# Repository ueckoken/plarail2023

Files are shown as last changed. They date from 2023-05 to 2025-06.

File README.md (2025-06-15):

# plarail2023

プラレールをIoT化して自動制御します

## これはなに？

このリポジトリでは電気通信大学工学研究部のプラレール企画のコードやドキュメントを管理しています。

## ドキュメント

プラレール企画に関する情報は以下のリンクにまとめます。

[https://ueckoken.github.io/plarail2023/](https://ueckoken.github.io/plarail2023/)

## コントリビュータのみなさんへ

GitHub Actions による CI/CD を走らせるために main ブランチへの直接コミットを禁止しています。 プルリクエストを発行してください。

PR の Reviewer には似たような PR で指定されている人を指定してください。内容ごとにタグを付けているので調べるときはぜひ活用ください。

PR が Approve されたら PR の Author が直接マージして下さい。

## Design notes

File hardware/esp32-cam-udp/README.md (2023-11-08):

# ESP-CAM-UDP

ESP32→(UDP)→NodeJS→(WebSocket)→browser

800x600 30fps 200ms

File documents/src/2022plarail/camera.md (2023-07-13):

# カメラ配信

## 車載カメラ配信

ESP-EYEというマイコンボードを一部のラジコン化したプラレールの先頭に取り付けており、車両からの映像を見られるように実装を行いました。ESP-EYEは、小さいながら単体でWi-Fi接続できてWebカメラとして利用することができる便利なボードです。

今回はプログラムとして[esp32-cam-mjpeg](https://github.com/arkhipenko/esp32-cam-mjpeg)を利用したのですが、これはESP-CAM側でストリーミングサーバーを建ててそこにアクセスするとmjpeg形式で動画がストリーミングされるというものです。そのため、単体ではWebRTCに直接配信できないので、canvasに描画されたmjpegをcaptureしてstreamを生成して、そのstreamをSkyWayに配信する配信用のサイトを構築して配信を行いました。これにより、ESP-CAMに接続されるクライアントが1つに限定されることでESP-CAMへの負荷も軽減されています。

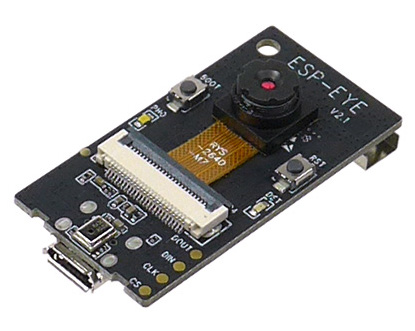
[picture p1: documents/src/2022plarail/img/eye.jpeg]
ESP-EYE


## Webカメラ配信

会場内の各所に設置されたWebカメラから各駅の現状を配信するために、SkyWayを用いて配信サイトを構築しています。仕組み自体は単純で、会場内にWebカメラとノートパソコンを設置しておき、配信用のサイトから駅ごとに固定のRoomIdで入室してカメラ映像の配信を行っています。

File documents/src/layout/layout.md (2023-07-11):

# レイアウト

2023.07.11現在のレイアウト案は以下の通りです。

```mermaid
flowchart LR
  shinjyuku["新宿(1)"]
  sakurajosui["桜上水(2)"]
  syako["車両基地"]
  chofu["調布(2)"]
  hashimoto["橋本(1)"]
  hachioji["京王八王子(1)"]
  syako --> chofu
  shinjyuku --> sakurajosui
  sakurajosui --> shinjyuku
  sakurajosui --> chofu
  chofu --> sakurajosui
  chofu --> hashimoto
  hashimoto --> chofu
  chofu --> hachioji
  hachioji --> chofu
  shinjyuku --> syako
```

```mermaid
flowchart LR
  s0 --> sa0
  sa0 --> ch0
  ch0 --> ha0
  ha0 --> ha1
  ha1 --> ch1
  ch1 --> sa1
  sa1 --> s1
  s1 --> s0
  ch0 --> hac0
  hac0 --> hac1
  hac1 --> ch1
  s0 --> pool
  pool --> ch0 
```

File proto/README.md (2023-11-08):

# protocol

全体で利用するProtobufを定義ファイルを格納するディレクトリです。

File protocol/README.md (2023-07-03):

# protocol

全体で利用する定義ファイルを格納するディレクトリです。

protobufやgraphQLを保存することを想定しています。

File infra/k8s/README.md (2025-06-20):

# Plarail2023 Kubernetes Deployment

このディレクトリには、Plarail2023プロジェクトをKubernetesで動かすためのマニフェストが含まれています。

## 前提条件

- Kubernetesクラスター（シングルノード）が動作していること
- `kubectl`がインストールされ、クラスターに接続できること
- Dockerがインストールされていること（ローカルビルドの場合）

## ディレクトリ構造

```
infra/k8s/
├── base/                    # 基本的なKubernetesリソース
│   ├── mongodb/            # MongoDB + Mongo Express
│   ├── emqx/              # EMQXメッセージブローカー
│   ├── state-manager/     # State Managerサービス
│   ├── auto-operation/    # 自動運転サービス
│   ├── frontend/          # フロントエンドダッシュボード
│   ├── proxy/             # プロキシサービス
│   └── nginx-ingress/     # Nginx Ingressルール
├── overlays/              # 環境別の設定
│   └── local/            # ローカル開発環境用
├── build-images.sh       # Dockerイメージビルドスクリプト
├── deploy.sh            # デプロイスクリプト
└── install-nginx-ingress.sh  # Nginx Ingress Controllerインストールスクリプト
```

## デプロイ手順

### 1. Dockerイメージのビルド

```bash
cd infra/k8s
./build-images.sh
```

### 2. Kubernetesへのデプロイ

```bash
./deploy.sh
```

このスクリプトは自動的にnginx-ingress-controllerがインストールされているか確認し、
必要に応じてインストールを行います。

## サービスへのアクセス

### NodePort経由

- Frontend (Ingress経由): http://localhost:30080
- EMQX Dashboard: http://localhost:31808
  - ユーザー名: admin
  - パスワード: password
- Mongo Express: http://localhost:30081
  - ユーザー名: admin
  - パスワード: password
- MQTT: localhost:31883
- Proxy (直接): http://localhost:30031

### Nginx Ingress経由（推奨）

deploy.shスクリプトは自動的にnginx-ingress-controllerをインストールします。
以下のURLでアクセス可能（すべてhttp://localhost:30080経由）：

- Frontend: http://localhost:30080/
- State Manager API: http://localhost:30080/api/
- EMQX Dashboard: http://localhost:30080/emqx/
- Mongo Express: http://localhost:30080/mongo-express/
- Proxy: http://localhost:30080/proxy/

### 手動でnginx-ingress-controllerをインストールする場合

```bash
# Helmを使用してインストール
./install-nginx-ingress.sh
```

## 管理コマンド

### ステータス確認

```bash
# すべてのリソースを確認
kubectl -n plarail get all

# Podのログを確認
kubectl -n plarail logs -f deployment/state-manager
```

### 削除

```bash
# すべてのリソースを削除
kubectl delete -k overlays/local/

# Namespaceごと削除
kubectl delete namespace plarail
```

## トラブルシューティング

### Podが起動しない場合

```bash
# Podの詳細を確認
kubectl -n plarail describe pod <pod-name>

# イベントを確認
kubectl -n plarail get events --sort-by='.lastTimestamp'
```

### PVCがPendingの場合

ローカル環境でStorageClassが設定されていない場合は、以下を実行：

```bash
# デフォルトのStorageClassを作成
kubectl apply -f - <<EOF
apiVersion: storage.k8s.io/v1
kind: StorageClass
metadata:
  name: standard
  annotations:
    storageclass.kubernetes.io/is-default-class: "true"
provisioner: kubernetes.io/no-provisioner
volumeBindingMode: WaitForFirstConsumer
EOF
```

## カスタマイズ

### イメージタグの変更

`overlays/local/kustomization.yaml`でイメージタグを変更できます：

```yaml
images:
  - name: plarail2023/state-manager
    newTag: v1.0.0  # 任意のタグに変更
```

### 環境変数の追加

各サービスのdeployment.yamlで環境変数を追加できます。

### リソース制限の設定

本番環境では、各コンテナにリソース制限を設定することを推奨します：

```yaml
resources:
  requests:
    memory: "256Mi"
    cpu: "250m"
  limits:
    memory: "512Mi"
    cpu: "500m"

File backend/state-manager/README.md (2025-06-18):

# State Manager

State Managerは、プラレールシステムの状態を管理するサービスです。

## 修正された問題点

### 1. エラーハンドリングの改善
- `log.Fatal`の使用を削除し、適切なエラーハンドリングに変更
- MQTTハンドラーのStart()メソッドの戻り値処理を修正
- リカバリーミドルウェアを有効化してパニック時のクラッシュを防止

### 2. リソース管理の改善
- データベースカーソルの適切なクローズ処理を追加
- データベース操作にタイムアウトを設定
- シャットダウン時のデータベース接続クローズ処理を追加

### 3. 設定の柔軟性向上
- 設定ファイルのパスを環境変数で指定可能に
- TLS設定のエラーハンドリングを改善

## 必要な環境変数

以下の環境変数を`.env`ファイルまたはシステム環境変数に設定してください：

```bash
# MongoDB接続設定
MONGODB_URI=mongodb://localhost:27017

# MQTT接続設定
MQTT_BROKER_ADDR=ssl://your-mqtt-broker:8883
MQTT_USERNAME=your-username
MQTT_PASSWORD=your-password
MQTT_CLIENT_ID=state-manager-001

# アプリケーション設定
APP_ENV=dev  # dev, test, prod

# オプション：設定ファイルのパス（デフォルト: ../settings/esp）
SETTINGS_PATH=/path/to/settings/esp
```

## TLS証明書

MQTTブローカーへの接続にはTLS証明書が必要です。`emqxsl-ca.pem`ファイルを実行ディレクトリに配置してください。

## 起動方法

```bash
# 開発環境
go run cmd/main.go

# 本番環境
APP_ENV=prod ./state-manager
```

## トラブルシューティング

### サービスが起動しない場合
1. 環境変数が正しく設定されているか確認
2. MongoDBが起動しているか確認
3. MQTTブローカーが起動しているか確認
4. TLS証明書ファイルが存在するか確認

### サービスが落ちる場合
1. ログを確認して具体的なエラーメッセージを特定
2. MQTTトピックの形式が正しいか確認（`target/id/method`の形式）
3. データベース接続が安定しているか確認

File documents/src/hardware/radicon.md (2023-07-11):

# ラジコン

ラジコンに関してはTWILITEを用いた速度制御を行うことで安定性の向上を目指したい。
基盤に関しては昨年にスバル君が作ってくれたものがあるので、今回はこれを基盤におこして小型化を目指したい。
また重心問題にも対応できるなら尚良い。

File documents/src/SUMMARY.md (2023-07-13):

# Summary

- [このドキュメントは何なのか](./topPage.md)
- [アーキテクチャ](./archtecture/archtecture.md)
  - [自動運転システム](./archtecture/auto_operation/outline.md)
    - [アルゴリズム](./archtecture/auto_operation/algorith.md)
- [ソフトウェア](./software/software.md)
  - [アルゴリズム](./software/algorithm/algorithm.md)
  - [プロトコル](./software/protocol/protocol.md)
    - [Protobuf](./software/protocol/protobuf.md)
- [ハードウェア](./hardware/hardware.md)
  - [ラジコン](./hardware/radicon.md)
- [レイアウト](./layout/layout.md)
  - [必要パーツ](./layout/item.md)
- [2022年プラレール企画](./2022plarail/2022plarail.md)
  - [システム構成図](./2022plarail/systemDiagram.md)
  - [レイアウト](./2022plarail/layout.md)
  - [状態管理](./2022plarail/state.md)
  - [自動運転](./2022plarail/automation.md)
  - [管理サイト](./2022plarail/site.md)
  - [カメラ配信](./2022plarail/camera.md)
  - [インフラ](./2022plarail/infra.md)
  - [ラジコン](./2022plarail/radicon.md)

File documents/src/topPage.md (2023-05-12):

# このドキュメントは何なのか

このドキュメントはプラレール企画についてのシステムだったり技術だったりの情報をまとめるために作りました。
ドキュメントを残すことで後輩への引き継ぎや初めて参加する人への説明をやりやすくしようという目的があります。
なのでみなさんドキュメントを書いていってくださいね。

## プラレール企画とは

プラレール企画は2020年の調布祭から始まった、プラレールを制御してみようという企画です。
やっていることは毎年少しずつ違っていますが、主にはポイント制御、車両の速度制御などを行っています。

## 2023年のプラレール企画の予定

2022年のプラレール企画が諸事情で爆散したので、2023年は2022年でのプラレール自動制御などを引き続きやっていくことになると思います。

また、システム構成についても見直して作り直そうということになっています。

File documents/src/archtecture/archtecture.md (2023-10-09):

# アーキテクチャ

2023.10.00時点での最新版のアーキテクチャ

```mermaid
flowchart RL

subgraph エッジデバイス
MQTTHandler <-->|"MQTT"| 通過在線検知センサー
MQTTHandler <-->|"MQTT"| ポイント制御器
end

subgraph 状態管理
管理画面 <-->|"connect"| StateManager
MQTTHandler <--> StateManager
StateManager <--> DB1[(state_db)]
end

subgraph 自動運転
AutoOperater <-->|"connect"| StateManager
AutoOperater <--> DB2[(diagram_db)]
AutoOperater <-->|"connect"| 管理画面
end

subgraph 映像配信
Webカメラ --> |"USB"| 配信サイト
ESP-EYE -->|"mjpeg"| 配信サイト
配信サイト -->|"WebRTC"| SkyWay
SkyWay -->|"WebRTC"| 管理画面
end

```

## 自動運転
昨年度は実装できなかった部分であるので、1から実装をする必要がある。
アルゴリズムの実装に関してはすでに#7にて議論している。路線の状態をグラフとして管理をする。
アルゴリズムにデータを渡すために色々をしなくてはいけないので、その部分に関しては別途実装する。

## 管理サイト
基本的にやりたいこととしては去年のサイトと同じだが、今回は状態を同期するためのプロトコルとしてconnect-webを採用したい。また、プラレールのレイアウトが微妙に変化することが予想されるのでフロントエンドの調整（SVG手打ち芸）が必要だが、可能ならこの部分を簡単にできるとなおよい。

## 状態管理
これまでとは異なるアーキテクチャで、列車の状態管理をモダンなIoTのアーキテクチャに近づけていきたい。
AWS IoTやAzureなどで利用されているアーキテクチャを模倣する感じで、MQTTでエッジの端末と通信してIOの状態の対応付けをバックエンド側で行うようにする。この部分は正直なところ、MongooseOSなどの既存の仕組みがあるが余裕があれば独自実装したい。
これまでは、KVSで管理していたがPodが死ぬと状態が失われるためアーキテクチャとしてはあまり良くない。
今回はアクセス頻度などを考慮して、MongoDBなどのNoSQLなDBで状態管理を行いたい。

## 列車検知
これまでのホールセンサーやCdSでは読み飛ばしが多くあった。今回はそうしたデータの読み飛ばしをなくすために、マイクロスイッチを用いた列車の通過検知と、列車が駅に停車した際にNFCタグを用いて列車を識別するような仕組みを実装したい。
基本手にはハードウェア側で大規模な処理をするわけではなく、イベントをhttp経由で通知してくれれば良い。（MQTTを採用するメリットは薄いような気もするがプロトコルの検討は必要かも）

## ポイント・ストップレール制御
昨年度と同様にESP32にサーボモータを接続して制御を行うことを検討している。
昨年度からの違いとして、MQTTでブローカーと接続してあげることで現地会場でのサーバー構築作業がなくなるので良さそうかなと思っている。httpよりも薄い感じのプロトコルらしく、普通にESPで問題なく動きそう。
ベースとなるコードはあるものの、実装が大きく変わるのでソースコードの変更は必要。

## カメラ配信
昨年度と同様にしてSkyWayを用いた映像中継を検討している。
車載カメラにはESP-EYEを採用してmjpegなどで受け取った映像を配信用PCからSkyWayに流すことを検討。
旧SkyWayがサービス終了するらしいので実装の変更は必要かもしれない。

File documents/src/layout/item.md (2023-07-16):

# 必要なレール一覧

[公式サイト](https://www.takaratomy.co.jp/products/plarail/lineup/rail/)を参考に必要なレールを検討。

## レール一覧

| コード | 商品名 | 必要本数 | 単価 | 個数 |
|:---:|:---:|:---:|:---:|:---:|
| R-01 | 直線レール | 12 | 300(4本) | 3 |
| R-03 | 曲線レール | 4 | 302(4本) | 1 |
| R-04 | 複線直線レール | 21 | 635(4本) | 6 |
| R-05 | 複線曲線レール | 10 | 587(4本) | 3 |
| R-06 | ニュー坂レール | 4 | 573 (2本) | 2 |
| R-08 | ストップレール | 15 | 507(2本) | 8 |
| R-10 | Uターンレール | 3 | 582 | 3 |
| R-11 | ターンアウトレール | 4 | 330(2本) | 2 |
| R-15 | 複線幅広ポイントレール | 12 | 540(2本) | 6 |
| R-24 | 複線わたりポイントレール | 2 | 577(2本) | 1 |
| R-28 | 複線ターンアウトレール | 2 | 786(2本) | 1 |
| J-14 | ブロック橋脚 | 12 | 669(6個) | 2 |
| J-22 | 複線ブロック橋脚 | 6 | 840(6個) | 1 |

## 合計金額

ヨドバシ.comにて見積もりをした結果，合計金額は`￥20,766`となった。([見積書](./estimate.pdf))

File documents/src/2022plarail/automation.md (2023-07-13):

# 自動運転

今年度の大きな新たな取り組みの1つが列車の自動運転です。

色々な方法があるので非常に悩んだ部分です。計画当初は、列車の位置をホールセンサーを用いて把握して、その位置に基づいてポイントを切り替えるようなシステムを想定しており、ポイントと列車の状態の管理に悩んででいました。

そんな中、Maker Fair Tokyoに訪れた際に「[東京大学プラレーラーズ](https://plarailers.com/)」さんという団体がまさにプラレールの自動運転を行なっていたので色々とお話を伺っていたところ、コラボのお誘いを受け調布祭でのコラボが実現しました。

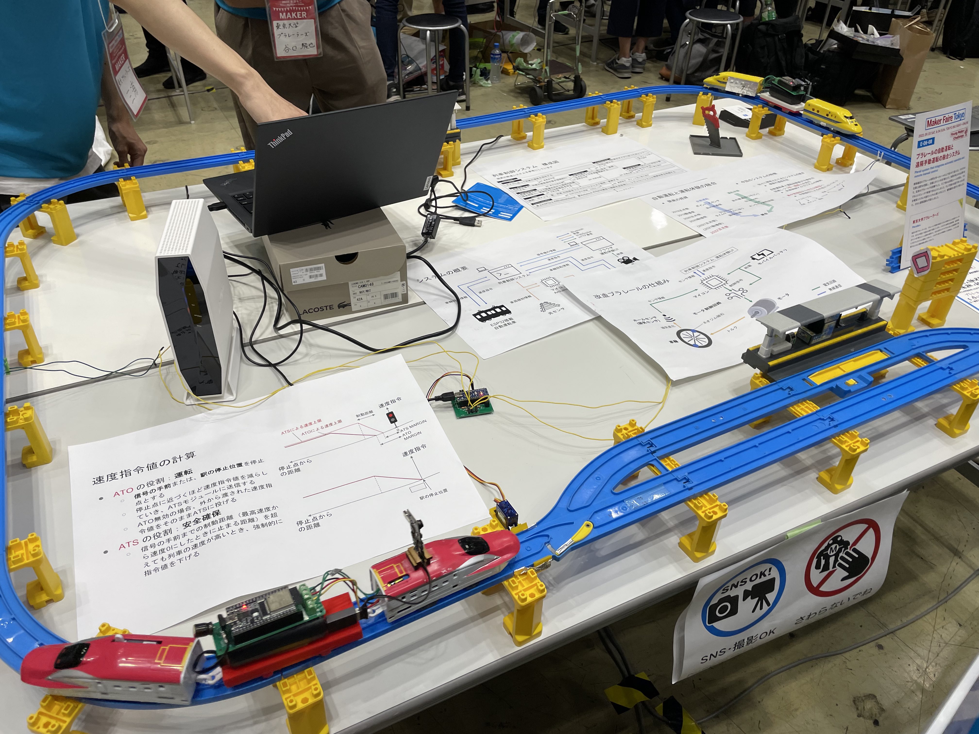
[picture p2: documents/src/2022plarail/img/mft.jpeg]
MFT


調整を行ったところ現在工研が開発しているシステムと組み合わせることが可能と言うことがわかり、プラレーラーズさんが実装した自動運転システムをauto operationとして組み込みました。

## 自動運転の仕組みについて

システムの詳細に関しては、プラレーラーズさんの資料やコードを参考にしていただきたいですが簡単に。

自動運転システムでは、配線図に示している`chofu_b5`のようなストップレールとホールセンサーからなる閉塞区間によって列車の位置を管理しています。プラレーラーズさんによるシミュレーションの画面のような感じです。列車ごとにダイヤを設定しており、それの列車の位置に応じてポイントとストップレールの切り替えを行っているようです。

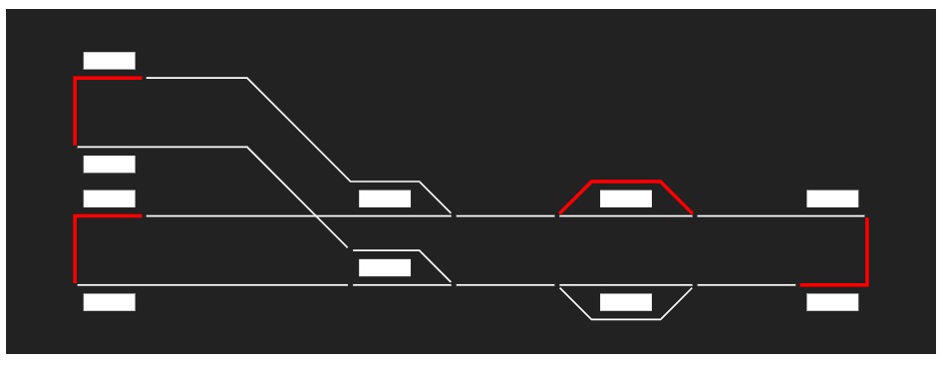
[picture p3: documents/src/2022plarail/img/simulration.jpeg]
シミュレーション


プラレーラーズさん側のシステムと工研のシステムでは扱っている情報や処理が異なるのですが、インターフェース部分や内部での値の取り扱いを工夫することによって連携を行っています。

ホールセンサーは、プラレールの車両の底の部分に取り付けられたネオジウム磁石の磁気を検知するセンサです。このセンサを用いることによって、列車がセンサーを通過したことを検知しています。検知したということを、jsonフォーマットのhttp経由でjson2grpcに送信してサーバーでgRPCに変換してauto operationに通知を行うようになっています。

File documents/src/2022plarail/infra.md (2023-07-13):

# インフラ

externalやinternalなどのサーバー群はすべてKubernetes基盤上にデプロイされます。Fluxcdを用いてGitOpsを実現しており、GitHubにてmanifestsを管理しています。

また、GitHub Actionと組み合わせてCI/CDを行っておりdeploymentのbranchにmergeされるとイメージがビルドされます。イメージの更新を検知するプログラムが走っているため、自動的にデプロイが更新されるようになっています。

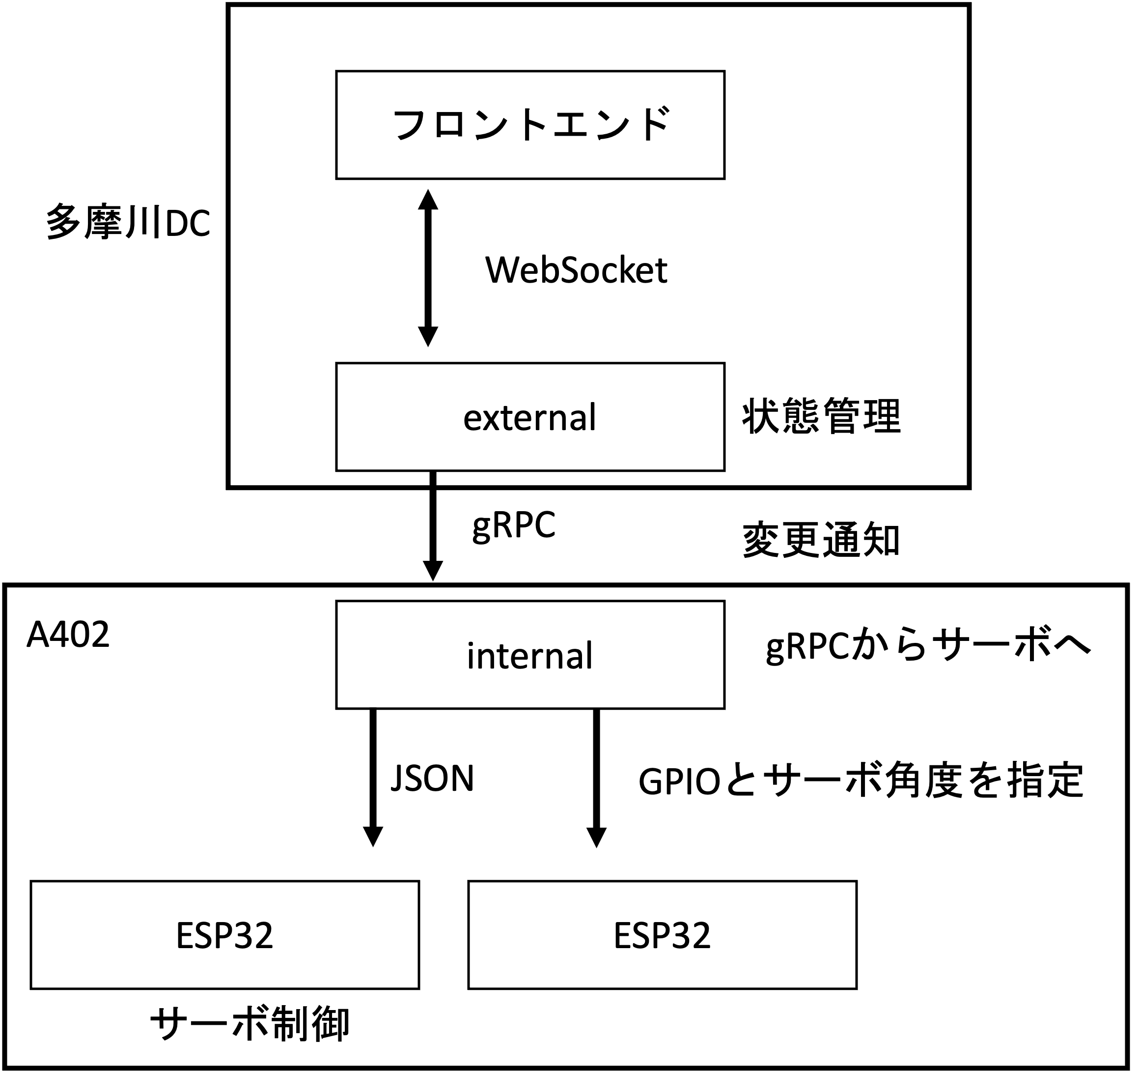
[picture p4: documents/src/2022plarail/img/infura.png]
インフラ構成


インフラの物理的な構成の概略を図に示します。

ここでは大きく、現地会場であるA402教室と多摩川DCに分かれています。現地会場では、デスクトップPCを配置しており、UbuntuのVM上でk3sを動かしています。多摩川DCは、20のごっちさんに提供していただいた自宅サーバー環境です。基本的にESP32と同一ネットワーク内に存在する必要があるinternalを除いて、externalやフロントエンド、auto operationなどはすべて多摩川DCに配置されています。

A402側でinternalサーバーをホスティングするために、大学に申請してグローバルIPを提供していただき、教室に設置したRTX1210をルータとしてネットワークを構築しています。

大まかなインフラ構成自体は昨年のプラレール企画とあまり変わっていないので、詳しくは昨年度のプラレール企画の記事や[ごっちさんのブログ](https://gotti.dev)を参考にしていただければ幸いです。

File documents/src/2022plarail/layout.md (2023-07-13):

# レイアウト

今年度のレイアウトを以下に示します。今年度は教室の関係で、昨年度よりも少し狭いレイアウトになりましたが、スペースを上手く活かして京王線を再現しました。

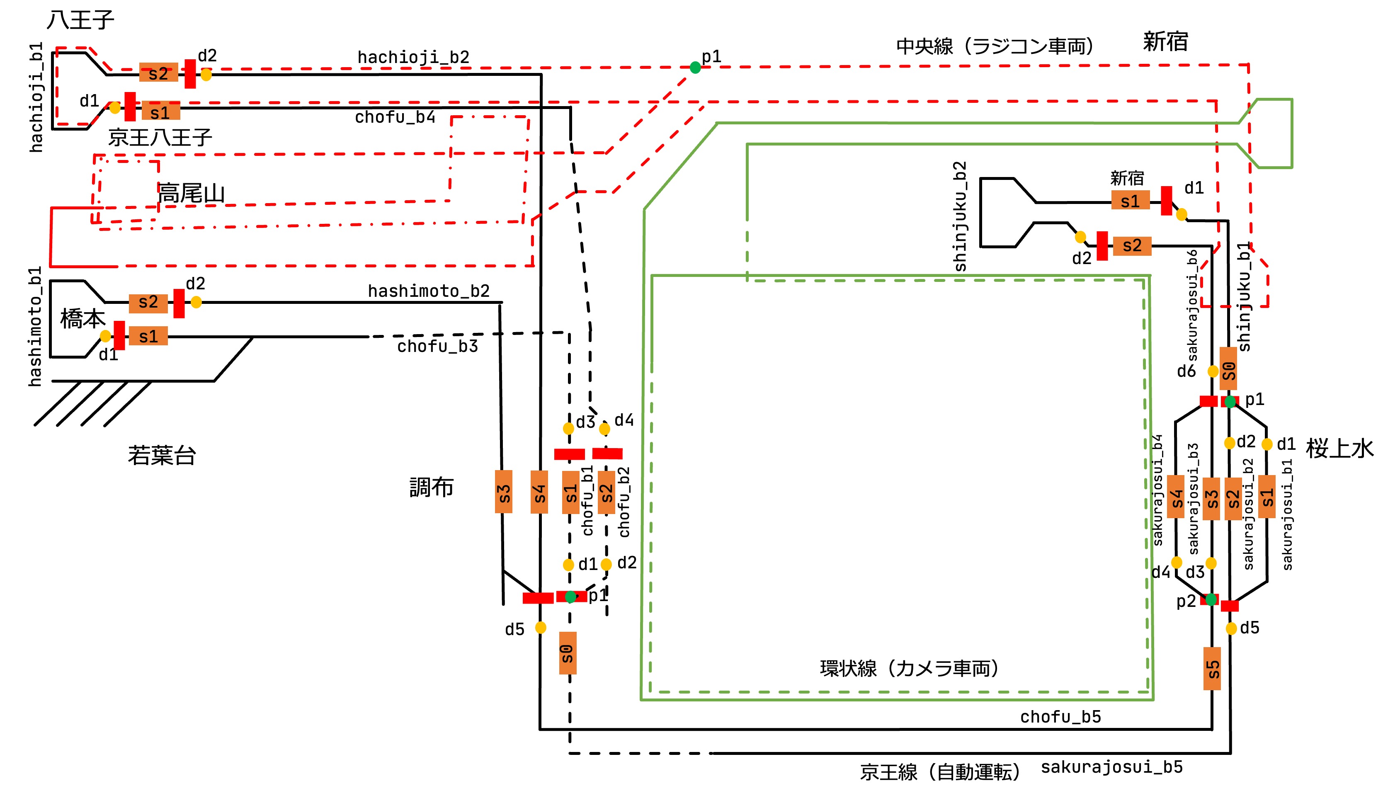
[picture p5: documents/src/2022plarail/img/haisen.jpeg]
配線図

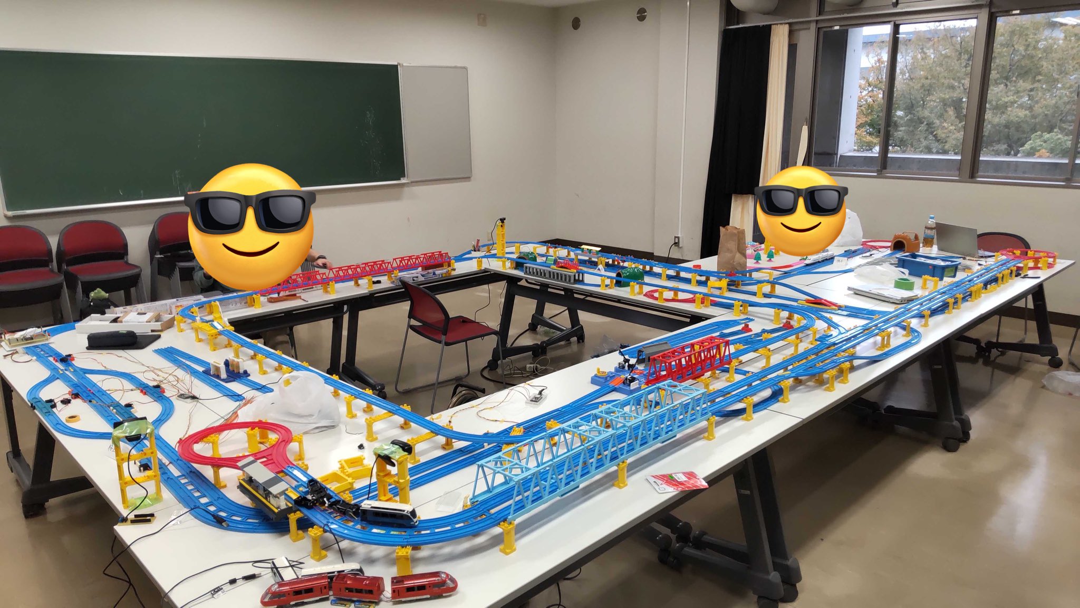
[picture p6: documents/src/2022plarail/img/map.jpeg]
配線した様子


いくつか路線がありますが京王線がシステムによる遠隔制御路線で、そのほかの中央線や環状線はラジコンが走る専用路線を担っておりポイントやストップレールの制御は行なっていません。

桜上水に待避線を用意して通過待ちを可能にしたり、調布駅を立体交差化したりと工夫しています。新宿駅のホームがなんで2つなんだ！というツッコミもあるかと思いますが、そこはバーチャル京王線ということで。

昨年度の反省（昨年は岩本町駅のように1つのホームに両方向の列車が来るようなパターンが存在していたためポイントの状態管理で組合せ爆発したり、列車が正面衝突する事故が多発しました）を生かして、ソフトウェア設計が難しくならないように物理的に調整したレイアウトになっており、列車が必ず一方通行に流れるように工夫しています。

プラレールに関しては、鉄道研究会から貸していただきプラレールの車両に関してはラジコン車両は主に工研で用意しました。

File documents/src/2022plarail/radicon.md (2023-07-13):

# プラレールラジコン化計画

## プラレールって？
プラレールとは古来より男児たちを中心に遊ばれている電車の形状をした玩具である。JR、私鉄を含む
豊富な車両があり、果てにはモノレールのプラレールも存在する。そんな男児なら一度は触ったことがあるであろうプラレール、その構造は実にシンプルなものだ。
電源を入れたらモーターが回転し電車がただ走り出すというものだ。端的にいえば前に走るだけであり、その動作は本来制御不能。しかし今回科学の力を用いてプラレールの速度制御を遠隔で行い、ラジコン化させる。

## 製作における要件定義
今回ラジコンプラレールの製作に当たって以下三つの要件を定めて開発を行った。

- 実機コントロールを用いて無線でプラレールをスムーズにリアルタイムで速度制御する。
- 改造の際、プラレールの外見を損なわないように部品を内部に収める。
- 量産しやすいようシンプルな構造にする。

そのため最終的にはラジコンプラレールを量産、調布祭で展示及びユーザーによる運転ができるようにする予定である。

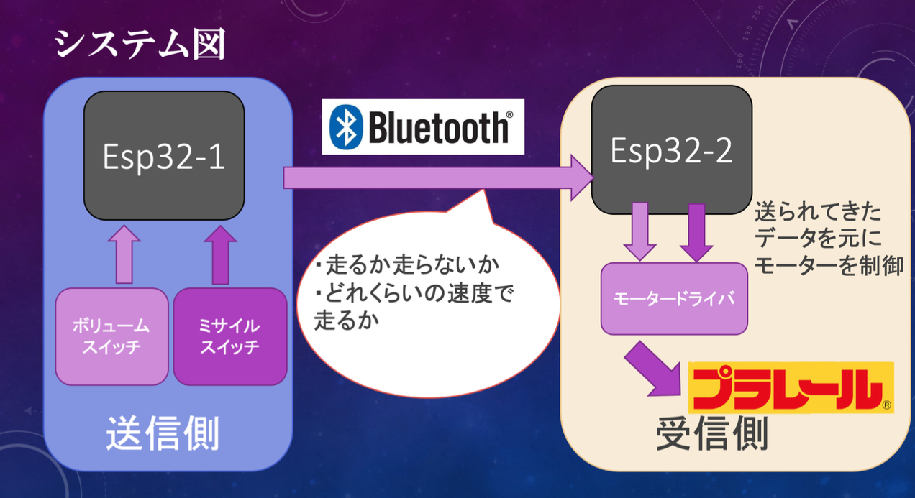
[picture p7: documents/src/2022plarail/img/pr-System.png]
システムズ図


ラジコンプラレールの大まかなシステムは以下の通りである。主にコントロールを担う送信側と、送られてきた
値を元にモーターを制御する受信側に分けられる。間の通信にはBluetoothを用いる。これによりある程度遠くから
運転を行うことが可能になり、消費電力も抑えることができる。

## ハードウェア
### 使用部品

- タカラトミー TAKARATOMY S52 [プラレール 小田急ロマンスカーGSE70000形]  
- ＥＳＰ３２－ＤｅｖＫｉｔＣ　ＥＳＰ－ＷＲＯＯＭ－３２開発ボード×2
-  DＤＲＶ８８３５使用ステッピング＆ＤＣモータドライバモジュール | ＤＲＶ８８３５使用ステッピング＆ＤＣモータドライバモジュール
-  ターミナルブロック　２．５４ｍｍ　２Ｐ　青　縦 | ターミナルブロック　２．５４ｍｍ　２Ｐ　青　縦
-  ピ分割ロングピンソケット　１×４２　（４２Ｐ） | 分割ロングピンソケット　１×４２　（４２Ｐ）
-  ＸＨコネクタ　ベース付ポスト　サイド型　２Ｐ　Ｓ２Ｂ－ＸＨ－Ａ（ＬＦ）（ＳＮ）
-  リチウム電池　ＣＲ１２３Ａ（ＣＲ１２３）
-  ００６Ｐアルカリ電池（積層電池）　９Ｖ　ゴールデンパワー
-  ミサイルスイッチ
-  ボリューム抵抗10k$¥Omega$
-  フルカラーLED

今回は以上の部品を用いてプラレールのラジコンを行った。使用プラレールは小田急ロマンスカーGSE。箱根湯本へ向かう小田急を代表する特急であり先頭車の展望席から見れるダイナミックな眺望が特徴.
車内も広々としていて綺麗なので皆さん是非乗ってみてほしい。新宿箱根湯本区間を約2500円で乗れるぞ！みんな乗ってみよう。

### 回路図

esp32をモータドライバに繋げたシンプルな一体化回路である。モーターとの接続はターミナルブロックを介しており
気軽に付け替えを行えるようになっている。マイコンの電源のみ接触不良を極力避けるためXHコネクタを使用している。
また基盤全体の大きさをプラレールサイズ(32mm×90mm)にとどめており、基本的な中間車に綺麗に収まるようになっている。
そのため外装を戻した際はぱっと見大きな変化が無いように見えるようになっている。
基板はユニバーサル基板なので気合いでハンダづけをしている。

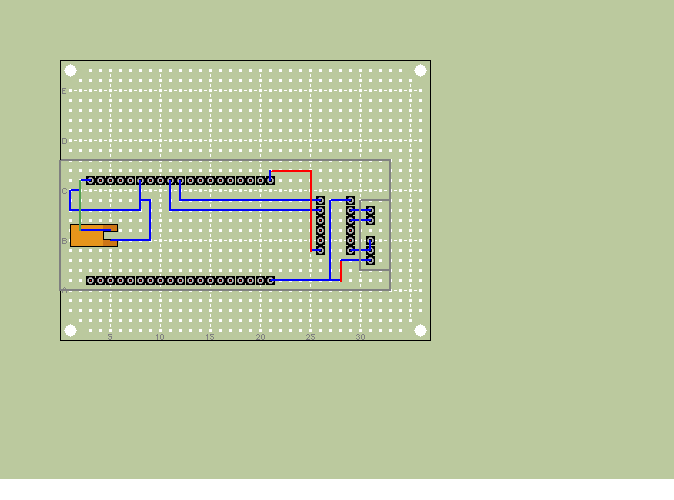
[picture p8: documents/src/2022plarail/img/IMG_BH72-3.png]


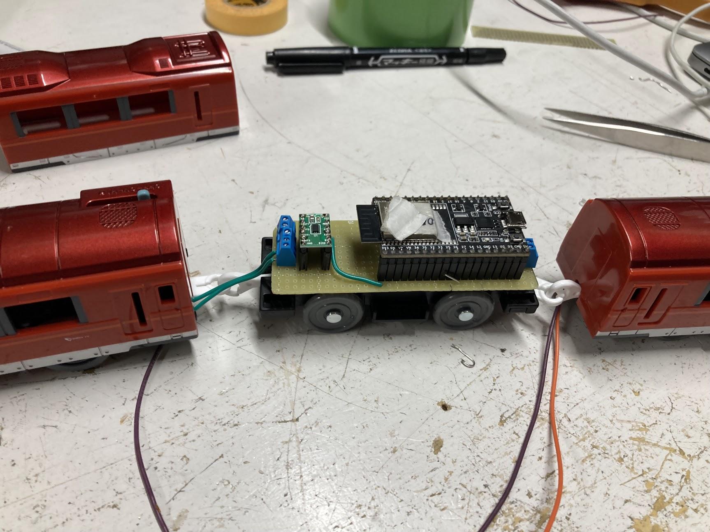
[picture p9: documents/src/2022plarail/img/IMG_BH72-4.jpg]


### プラレールの改造
先頭車に動力、中間車と後尾車は空というのがプラレール車両の基本的な構造である。
そのため、中間車に先ほどの回路、後尾車にバッテリーという車両構成になった。先頭車の動力は
モーターから配線を伸ばす以外の改造はしておらず、重りとして絶縁させた乾電池の搭載を行っている。
また内部に部品を詰める都合上内部の柱は破壊してある。これにより外装を外しやすくなり、気軽にメンテナンスを
行えるようになった。

改造したプラレールの様子である。ぱっと見は元のプラレールとの大きな変化もなく
綺麗に収まった姿になっている。窓から一部のパーツが見えてしまっているが、排熱も兼ねているので何も悪いことだけではない。（上から見れば割とわからんしね…）

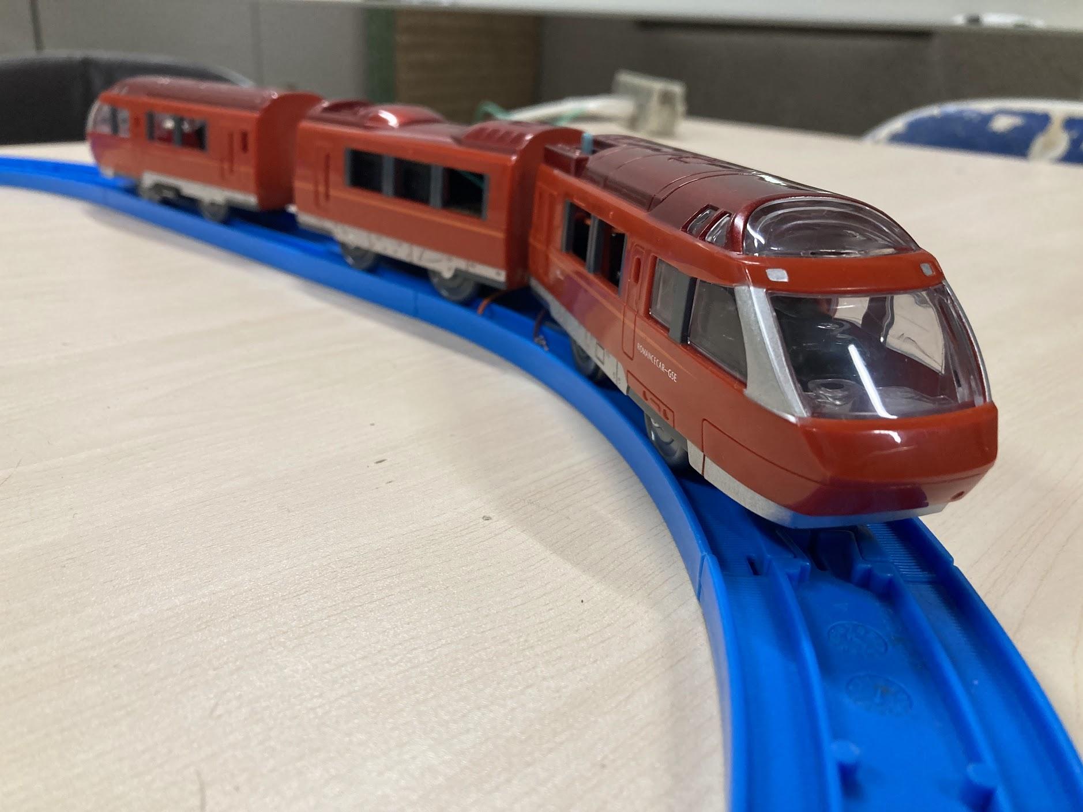
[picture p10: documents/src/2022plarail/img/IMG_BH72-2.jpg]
製作したプラレール車両


### プラレールコントローラー
速度制御はボリューム抵抗を介して行っている。ボリューム抵抗のつまみを回すことでプラレールの速度を制御することができる。
つまみを最大まで回すことでプラレールは最高速で走り出す。
また発車できるか否か、
ちゃんとBluetooth接続がなされているかの確認のため下記の
ようにフルカラーLEDを搭載している。そのため今の状態が視覚的にわかりやすくなっている。
解説するとランプが赤の時、Bluetooth接続が完了したことを表している。この時に（かっこいい）ミサイルスイッチをONにすることで
ランプが青になりプラレールは発信することができる。コントローラーの機能としては最低限あるが
外装はまだ出来ておらず大変大味な仕様となっている。

### バッテリーについて
このラジコンプラレールの中で地味ながらも重要な存在はバッテリーである。
マイコン用の電源とモーター用の電源の二つが必要となり、尚且つ内部に
パーツを収める必要があった。最後尾車にバッテリーは収納したが大きさの制限は大きく
あまり大きい電源を搭載することは出来ない。そこで以下のようにした。マイコン電源はesp32の5V、GNDから供給されており
esp32の電源供給の必要電圧のラインは7~12Vとなっているので9V電池を使用した。
内部のレギュレーターで最終的に3.3Vまで落としてくれるらしいので破損の心配もない。
モーター電源はカメラ用電池で使用されているCR123aを使用。サイズが小さく尚且つ定格電流、電圧も申し分ないという
理由から採用がなされた。

## ソフトウェア

#### 送信側
ペアリングするesp32のMACアドレスを元にまずペアリングを行う。ペアリングは無線イヤホンが飛び交っている状態や
なんか気分によっては繋がりにくい時がある。また受信側のesp32の電源をONにしてからでないと繋がりにくくなる。
というかなんか繋がらない。Bluetooth接続後はコントローラーのランプが赤く光る。この状態でボリュームを回しても電車は
走り出さない。ミサイルスイッチの電源をONにすることでランプが青に代わり発車できるようになる。この辺は信号機の色の変化を意識
している。結局このコントローラーはBluetoothを介して配列型の値を送信しておりスイッチの動作によって配列型の値が変わるようになっている。
今回は主に二つのデータを送信しており発車するか否かと、列車の速度の値である。列車の速度は0~255の256段階となっておりボリュームの位置で決まる。
ボリュームから測ったアナログ入力の値max4095を16で割った数を挿入し送り出しているのだ。Bluetoothからのデータ送信はリアルタイムで行われており
常に速度を制御することが可能となった。また配列型のデータを遅れることからその拡張性はとても大きい。

#### 受信側
速度制御ということでPWM制御を行っている。詳しい説明は先人たちがきっとしているので省くが、Bluetoothを介して送られてきた0~255の値を代入し
任意の速さで動かせるようになっている。余談というべきか、当然の話といえば当然なのだがesp32を使用しているので
スマホからの制御も実は可能である。

## 残る課題と今後の展望
まぁ大体上手くいったのだがまだ課題が多く残っている。

まずこのプラレール車両の構成上満足に前後に走ることが出来ない。
重量バランスが崩れたこともありすぐ脱線したりするのだ。
これの解決策としてプラレールの前後、先頭車最後尾車両方にモーターを搭載するということを考えている。プラレールの車両には
連結することが可能な車両がおり、結果前後にモーター車両が来ることになる。こちらの車両を使用することで満足に前後運転ができるようになるだろうと考えている。
また重量バランスが狂った弊害としてもう1つ電池残量によっては坂を登れなくなってしまった。
中間車後尾車に対して先頭車両が相対的に軽くなってしまい、坂を登る際に前輪がウィリーしてしまうのだ。
これに関してはモーターをより強力なものに換装しかつ先端部に重りを搭載することで解決しようと考えている。

次にコントローラーだがこれはまず見た目が雑すぎるのだ。基板に直接諸々を乗っけたという状態の上外装がないので持ちにくさにも繋がっている。
この辺は改造できる点が多い。まず外装を作り、コントロラー部分をマスコンのようなハンドルへの変更。
せっかく電車を運転しているのでできるならマスコンのようにしたいと考えている。
またプラレールはモーターで動く都合上モーターのノイズしかならない。そこで走行中車両の発車音、走行音がなればより
面白みが出るのではないか？と考えている。カメラを先頭部に取り付けラジコン操作ができるように
なればまさに「電車でGO」である。理想系としてはこの形の完成を目指している。

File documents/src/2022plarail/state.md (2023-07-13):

# 状態管理

IoTシステムの基本的な機能である状態管理を担っているのが、externalとinternalの2つのサービスです。ここら辺のシステムは昨年度のものをそのまま引き継いでいます。

IoTシステムにおける状態管理について簡単に説明すると、システム上の状態と現実のハードウェアの状態を一致させるということです。例えば最近よくあるようなスマホから電気をON/OFFできるようなライトがあった時に、サーバー上ではライトの現在の状態(ライトがついているのか消えているのか)を保持しており、スマホからライトを消すという指示がくるとサーバー上の状態を更新するとともに、現実のライトもOFFにします。もし状態管理がうまくいっていないと、システム上だとライトが消えているのに現実のライトは点いているというような事態に陥ってしまうのでとても重要な部分です。

また、この状態管理によってシステムの状態とハードウェアの状態が一致していることが保証されていると、ソフトウェアではより抽象的にハードウェアを扱うことが可能になります。

さて、今回のシステムではexternalがポイントとストップレールの状態をKVS(Key Value Store)で保持しています。このexternalの状態が変化するとその変化がinternalを介してサーボを制御するESP32に伝わることで現実世界のポイントが動きます。たとえば、`sakurajosui_b1`というストップレールをONにすると、

1. ストップレールをONにするボタンが押される
2. クライアントからexternalのAPIを叩く
3. externalで状態(ON/OFF)を更新して、操作するポイントの名前と状態をinternalへ伝える
4. externalから渡された状態に基づいて、そのポイントを管理するESP32に対してサーボの角度を指定するAPIを叩く
5. ESP32で指定された角度にサーボが動き、ストップレールが動く

というような流れになっておりそれぞれで抽象化されているので、上から下へ流れるにつれてレイヤが下がっていくイメージです。

実装的な面で言うと、externalとinternalはそれぞれgolangで実装され、gRPCを用いて話すようになっており、フロントエンド側からはJSON形式のhttpでリクエストを受けつけるようになっています。ここら辺もconnectとかを使ってprotobufを使うように統一できると良さそうですね。

また、internalのサーバーはESP32と同じネットワーク上に存在しており、ESP32に固定IPを割り振ってそのIPアドレスをinternal側で管理することで実装しています。最近のIoTシステムだと、ESP32から直接クラウド上のサーバーにアクセスして状態の変更を監視するみたいなパターンが多いので少し特殊かもしれません...?

MongooseOSとmDashを使ってクラウドにするぞー！という計画はあったのですが、接続できる台数の制限があったり、1からこの部分のコードを書き直していると他の部分が追いつかないなどがあったので断念しました...。もし次回があればそこらへんも挑戦してみたいです。

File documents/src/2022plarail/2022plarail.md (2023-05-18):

# 2022年プラレール企画

2022年のリポジトリは[こちら](https://github.com/ueckoken/plarail2022)

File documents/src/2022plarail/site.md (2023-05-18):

# 管理サイト

昨年は完全オンライン開催だったため、観客側がポイントを遠隔で操作するために操作用のサイトを用意していました。しかし、今年度は対面開催かつ自動運転であるため基本的に来場者がポイントを操作することはありません。そのため、メンテナンスとモニタリング用にポイント・ストップレールの状態の確認と把握、カメラ映像の確認ができるサイトを構築しました。

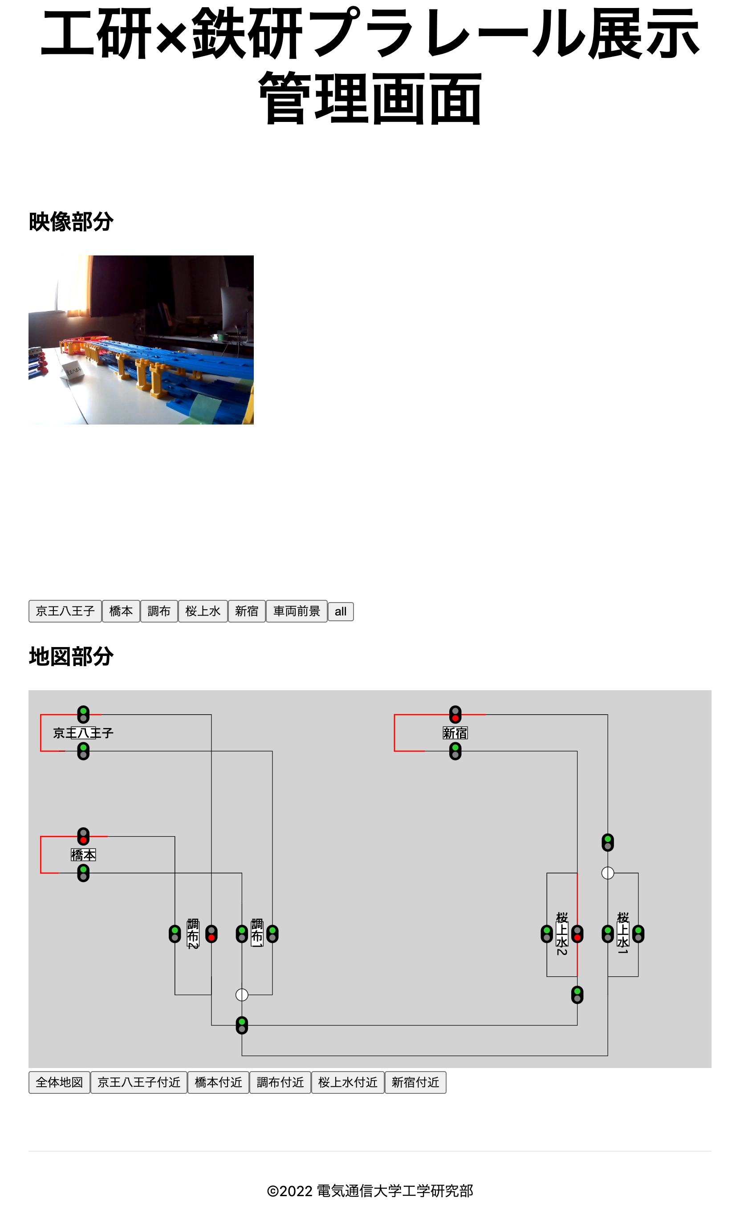
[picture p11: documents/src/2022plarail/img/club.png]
配信画面


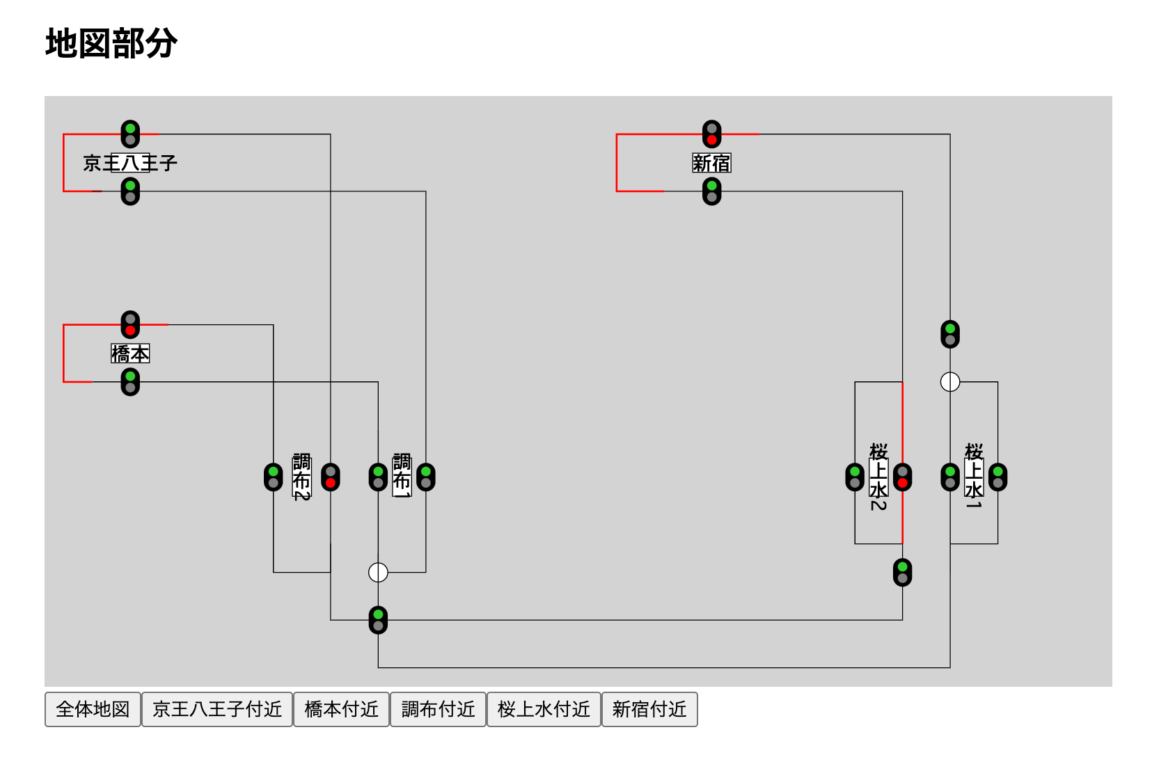
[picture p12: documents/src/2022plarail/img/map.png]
列車の状態表示


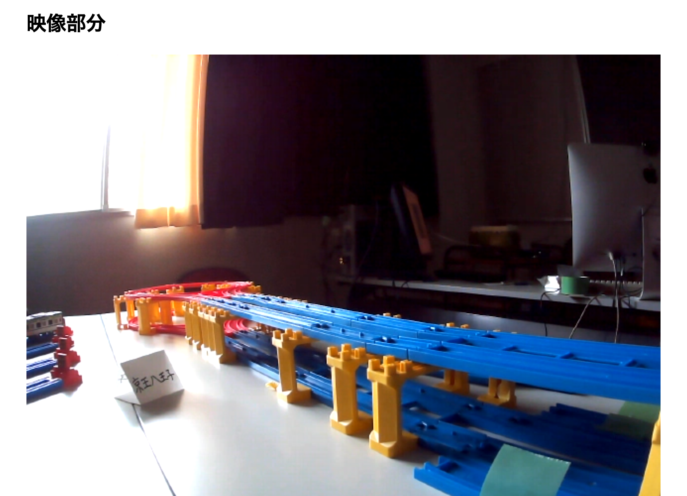
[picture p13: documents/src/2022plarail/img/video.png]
配信映像


管理画面の上部には、会場の各駅ごとに設置されたWebカメラの映像が投影されており一括して状態を確認することができます。画面下部では、現在のレールの状態が表示されています。

それぞれの信号がストップレールと対応しており、クリックするとストップレールのON/OFFが切り替わります。また、分岐になっているところをクリックするとポイントが切り替わります。

フロントエンド側とexternalのサーバー側とでWebSocketにて通信を行なっており、リアルタイムで状態の反映が行われるようになっています。

また、路線上で赤色にハイライトされている部分は閉塞区間が閉になっている部分で、その区間内に列車が存在することを示しています。

フロントエンドの実装は、Next.jsで行っています。昨年度のプラレール企画のものをベースとして今年度のレイアウトへの反映や調整を行いました。

画面下部の状態表示の部分はSVGを直接書き換えて実装しており、ReactでSVGをwrapするComponentを作成して下のように全てのパーツを座標指定して配置してあります。（手打ちで全部の座標を打ち込むのはなかなか辛かったのでツールで自動化したいです...）

```jsx
<Rail
  // hachioji_b2
  positions={[
    { x: 120, y: 40 },
    { x: 300, y: 40 },
    { x: 300, y: 500 },
  ]}
  trains={[]}
  isClosed={blockState["hachioji_b2"]}
/>
```

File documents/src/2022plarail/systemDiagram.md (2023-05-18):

# 2022年のシステム構成図

今年度のシステム構成図を以下に示します。

昨年度のプラレール企画のアーキテクチャを引き継いで今年度に新たにいくつかの機能を追加した形になります。今年度新しく追加した部分は次の通りです。

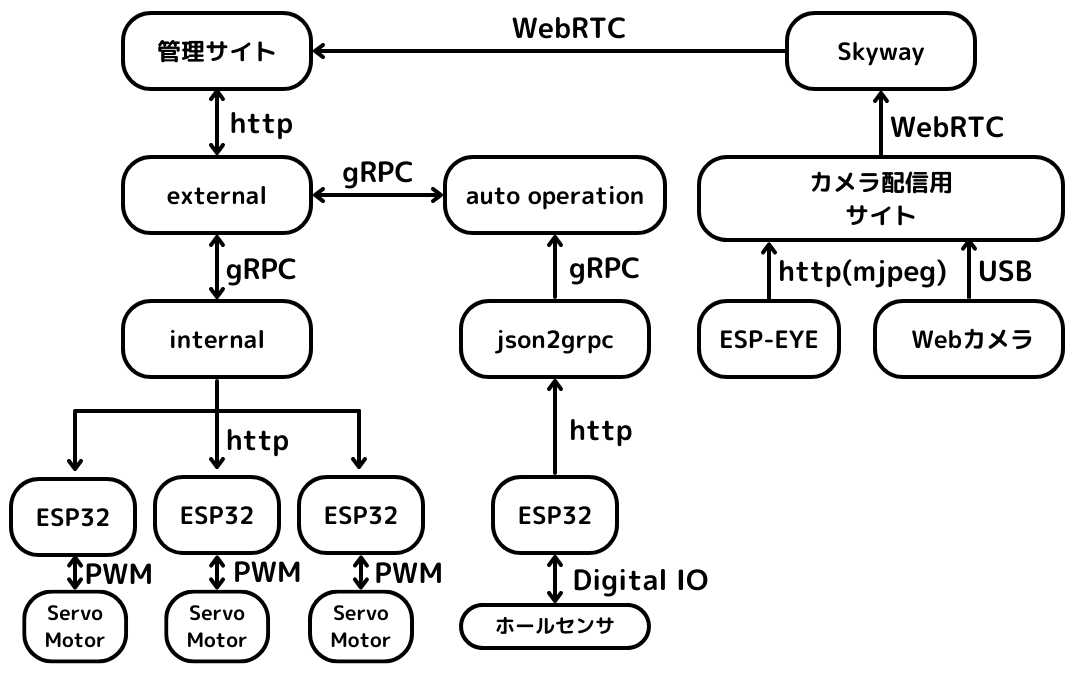
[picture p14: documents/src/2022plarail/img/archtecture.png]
2022年のシステム構成図


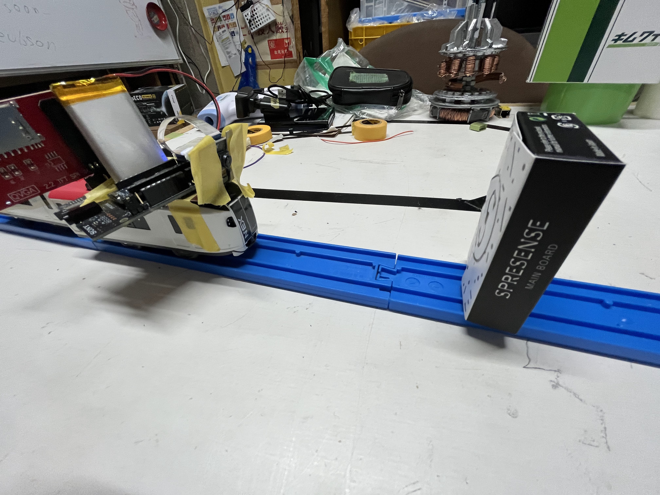
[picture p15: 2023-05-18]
documents/src/2022plarail/img/eltres.jpg

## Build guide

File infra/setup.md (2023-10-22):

# k8sクラスタのセットアップ方法

1. k8sクラスタにログインできるようにする
2. Fluxのインストール
[https://](https://fluxcd.io/flux/installation/)
3. GithubのPAT (Personal Access Token)を取得する。
4. 以下のコマンドを実行する。

```zsh
flux bootstrap github \
--components-extra=image-reflector-controller,image-automation-controller \
--owner=ueckoken \
--repository=plarail2023 \
--branch=main \
--read-write-key \
--path=./infra/manifests
```

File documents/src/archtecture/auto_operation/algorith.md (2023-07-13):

# 自動運転アルゴリズム

列車は以下のようなアルゴリズムに沿って自動運転を行う。

# 概要

全ての列車の位置と閉塞は以下のようなグラフによって管理される。

```mermaid
flowchart LR;
  A["A(1)"]-.-|2|B;
  B["B()"]-->C;
  C["C()"]-->D;
  C-->E;
  D["D(3)"]-->C;
  E["E()"]-->C;
  C-->B;
  B-->A;
```
それぞれのノードが駅，エッジが閉塞を表している。

なお，これ以外に列車は以下のような状態を持つ。
- 列車の位置
- 列車のPriority(列車の種別のようなもの)
- パス(列車が通るべき経路でノードのリスト)

Priorityは0から始まる整数で，値が小さいほど優先度が高い。

## PathPlanner

ある列車の現在の位置と目的地を受け取り，その列車が目的地に到達するためのPathを返す。
PathPlannerはDFSによってグラフを探索して，目的地に到達するまでに通る全てのノードのリスト(Path)を返す。

## TrainController

グラフ上の各ノード対して以下の処理を行う。

なお，この処理はPriorityが高い順番に行う。

```mermaid
flowchart TD
  idstart{{"開始"}}
  idstart --> id0{{"Nodeに列車は存在するか?"}}
  id0 -->|yes| idQ{{"現在の駅のNodeをPathから削除する"}}
  idQ --> id
  id0 -->|no| idend{{"終了"}}
  id{{"列車のPathの長さは0か？"}}
  id -->|yes| id1{{"DiagramManagerから次のPathを取得する"}}
  id1 --> id6
  id6{{"Pathを取得できたか?"}}
  id6 -->|no| idend
  id6 -->|yes| id7{{"Pathを列車にセットする"}}
  id7 --> id2
  id -->|no| id2{{"Pathの最初のNodeを取得する"}}
  id2 --> id3{{"次の目的地までのEdgeは存在するか？"}}
  id3 -->|yes| id4{{"次のNodeまでのEdgeを削除する"}}
  id4 --> id5{{"Nodeから列車の情報を削除する"}}
  id5 --> idend
```

それぞれの操作と条件について説明する。

### Nodeへの列車存在確認  

列車が存在しないNodeに対しては処理をする必要がないので，呼び出された時点で終了する。この処理を実現するために，Nodeは停車している列車のIDを持っている。

### Path
列車には列車が通るべき経路(パス)が設定されている。列車があるノードに停車した際には，現在停車しているノードをパスから削除して次に停車すべきノードをパスから取得する。

これを毎回のノードで実施することによって，最終的に列車は目的地に到達することができる。目的地に到達した時点でPathの長さが0となるので，DiagramPlannerへ問い合わせを行う。

### Edge

現在のノードから次のノードまでのEdgeは1意に定まる。列車はこのEdgeを通らないと次のノードに到達することができないため，駅から発車するためにはこのEdgeが存在する必要がある。

Edgeが存在して，列車が発車しようとする際にEdgeを削除するが，この操作には以下の特例がある。
**Priorityが0の列車はさらに次のノードへのエッジも消す。つまり2つのエッジを削除する**

ただしこの操作を行うには以下の条件がある。

- 中間の駅のCapasityが1より大きいこと

この条件を満たさない場合は，通常通り1つのエッジを削除する。
## DiagramManager

列車の目的地を管理するサービス。
それぞれの列車の目的地を状態として管理しており，TrainManagerからの要求に応じて目的地とPriorityを返す。

それぞれの列車に設定されているPriorityと目的地は管理画面から設定できる。また，それぞれの目的地とPriorityは優先順位付きのQueで管理されている。

基本的には折り返しが可能な2区間での往復運転を行うように設定されることを想定している。ただし，物理的な制約として折り返しができるのは終点のみである。

## 車両の取り出しに関して

車両の取り出しに関しては，以下のような処理を行う。

今回のレイアウトでは車両基地を設けず，駅に停車している任意の列車を取り出してレイアウトから外すことができるようにする。

レイアウトから取り出した車両は，別に用意しているNFCリーダーに車両のIDをかざして，システム上から対応する列車に対して以下の処理を行う。

- 当該列車によって削除されているEdgeが存在する場合は，そのEdgeを復元する
- 当該列車のPathに停車すべきNodeが残っていた場合は，Nodeを全て削除して列車のPathをNULLにする

これにより，どのような状態であっても車両を取り出すことができるようになる。

また，取り出しやすくするためにDiagramPlannerにおいてある駅で停車するという指示もできるようにしておく。

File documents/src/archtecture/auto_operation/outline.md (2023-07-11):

# 自動運転システム

```mermaid
flowchart TD

subgraph 自動運転
TrainController <--> StateManager
DiagramManager --> PathPlanner
PathPlanner <--> TrainController
DiagramManager <--> DB2[(diagram_db)]
DiagramManager <-->|"connect-web"| 管理画面
end

subgraph 状態管理
管理画面 <-->|"connect-web"| StateManager
EventHandler <-->|"connect"| StateManager
StateManager <--> DB1[(state_db)]
end
```

## 用語

プラレール企画で利用する用語の定義を説明する。

ここには2つのレイヤが存在し，列車の走行位置や閉塞の状態をグラフとして管理している`仮想レイヤ`と，実際のプラレール上のストップレールのON/OFFやセンサーの情報を扱う`物理レイヤ`が存在する。

それぞれのレイヤは完全に独立して機能して，`物理レイヤ`の状態は`仮想レイヤ`によって決定され，`仮想レイヤ`の状態の更新は`物理レイヤ`からの情報によって行われる。

### 仮想レイヤの用語

- 閉塞  
現実の鉄道システムからの用語。鉄道の線路を区切る単位。閉塞内には一つの列車しか存在できない。閉塞内に列車が存在する状態を`閉`，存在しない状態を`開`という。

- 閉塞グラフ  
閉塞の関係を表現した有向グラフ。閉塞をエッジ，駅をノードとして表現する。
閉塞が`閉`となっている区間はエッジが存在せず，閉塞が`開`となっている区間はエッジが存在する。また，各ノードは駅の情報以外にその駅に停車している列車の情報を持つ。  
上り線と下り線は別々のノードとして定義して一周するようなグラフであり，あるノードからあるノードへのパスが必ず存在する。

- 列車番号  
それぞれの列車に対して一意に割り当てられる番号。列車の識別に用いる。  
列車IDは各列車に貼り付けられるNFCのIDと一対一対応する。

- 駅のCapacity  
駅に停車できる列車の数を示す。駅に存在するプラットフォームの数と一致する。

### 物理レイヤの用語

- 構内閉塞  
駅に2つ以上のプラットフォームが存在する場合，その駅の閉塞は構内閉塞となる。構内閉塞は駅のCapacityと一致する。なお，構内閉塞は閉塞グラフには含まれない。

- ストップレール  
プラレールにおいて列車を停止させるために利用する特殊なレール。ストップレールのON/OFFを切り替えることで列車を停止させることができる。

- NFCタグ  
プラレールの車両に貼り付けるIDタグ。それぞれのタグには8byte?のIDが割り振られており，このIDと列車の番号の対応付けを行うことで列車の識別を行う。

- NFCリーダー  
プラレールにおいてNFCタグのIDを読み取るために利用するリーダー。それぞれのストップレールの下に設置しており，列車が停止したときにNFCタグのIDを読み取ることができる。

- 通過検知センサー  
プラレールにおいて列車の通過を検知するために利用するセンサー。センサーのON/OFFを切り替えることで列車の通過を検知することができる。物理的にはマイクロスイッチを用いる。

- ESP32  
サーボモータの制御やNFCリーダー，通過検知センサーの制御を行うために利用するマイコン。Wi-Fiを用いて通信を行う。

- サーボモータ  
プラレールのストップレールを制御するために利用するモータ。指示をした角度へ回転する。

## それぞれのサービスの機能
### StateManager

現在の状態を管理するためのサービス。状態をデータベース上に保存して，他のサービスや管理画面からの要求に応じて状態の更新と取得を行う。  
物理レイヤの状態と仮想レイヤの2つの状態を管理する。
### DiagramManager

列車の目的地を決定するサービス。列車ごとに運行情報を管理して，TrainControllerからの要求に応じて目的地を返す。

### PathPlanner

列車の経路を計算するサービス。経路情報のグラフを元にして，DFSによって現在の列車の位置から目的地までの経路を算出して返す。
### TrainController

列車の運行を管理するためのサービス。列車の運行を管理するために必要な情報をStateMangerから取得して，PathPlannerによって計算された経路を元にして列車の運行を制御する。

### EventHandler

列車が通過した場合と停車中の列車からNFCタグのIDを読み取った情報をMQTTを通して受け取り，その情報を元にしてStateManagerに対して状態の更新を要求する。

## 管理画面

現在の状態を確認するための管理画面。StateMangerから状態を取得して表示する。  
また，DiagramManagerに対して運行情報の更新を要求することができる。

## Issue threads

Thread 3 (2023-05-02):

ドキュメントを作る

kienn-HCl, 2023-05-02:
初めて参加する部員がプラレール企画について把握しやすくするために、きちんとドキュメントを整備したい。

kienn-HCl, 2023-05-11:
gh-pagesブランチにmdbookでビルドしたのをデプロイするようにした。
このリポジトリのsetting私いじれないみたいだからGithub Pages の設定やってくれ @csenet

csenet, 2023-05-11:
@kienn-HCl
設定しておいた。
https://ueckoken.github.io/plarail2023
一応、Adminに昇格させておいたので自由にSettings触れるようになったはず。

csenet, 2023-07-16:
ある程度ドキュメントは完成したのでClose

Closed 2023-07-16.

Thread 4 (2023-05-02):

BLEを利用した位置測位の検証

csenet, 2023-05-02:
プラレールにBLEビーコンを搭載することによって測位を実現したい

## メリット
- ホールセンサによる通過検知と比較して安定した検知ができる
- プラレール内部に小型ビーコンを取り付けるだけで良い

## デメリット
- 位置測位のアルゴリズム構築が面倒
- ホールセンサと比較すると費用がかかる

csenet, 2023-06-29:
BLEを用いた位置即位では正確性に欠けるため、別の方法を検討することにする

Closed 2023-06-29.

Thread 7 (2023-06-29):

自動運転用のアルゴリズムを実装する

csenet, 2023-06-29:
# やりたいこと

**MUST**
- 列車が衝突しない

**SHOUD**
- 最悪のパターンが考慮されている
- 車両ごとの優先度が考慮されている(特急や快速など)

# 前提条件

今回のアルゴリズムとしては列車をいわゆるネットワークにおけるパケットのように見立てて、駅をルータとして駅で列車の情報を取得したタイミングでこのアルゴリズムが呼び出されて、列車が次に向かうべき駅とルートが決定される。

列車には優先度と目的地が定められており、一緒に入力として与えられているとする。

# 入力と出力の要件

自動運転用のアルゴリズムに対する入力は任意の有向グラフとして与えられる。
グラフの入力は、連結リストによる入力を想定する。
列車が存在しており現在通行ができない区間（閉塞が閉の区間）に関してはパスが存在しない。
必ずしも最適経路でなくても良いが、なるべく経路数は少ない方が好ましい。

出力結果としては、
- 現在列車がいる位置から出発して良いのか
- 次の列車の目的地はどこか
- 列車が次に通過するエッジの情報
が最低限出力されていれば良い。なお、出力のフォーマットに関してはソフトウェアで扱いやすい形式であれば任意。

また、全ての車両に対して計算を行うため、計算時間はなるべく少ない方が好ましい。

- 優先度の考慮について

現時点では仕組みとして全ての列車が運転停車する形になってしまっているが、可能ならば通過待ちをできるようにしたい。
駅を通過するという処理を実装するためには、列車の優先度を定める必要がある。
この点に関しては多少検討がいるかもしれない。

# 実装の方針

そこまでグラフが複雑になることはないのでDFSで探索するのが良いかもしれない。計算量を抑えるために増加道法など...?

kienn-HCl, 2023-06-30:
増加道法は二部グラフの最大マッチングだったり最大流問題？ってのを解くのらしいから最短経路を求めるアルゴリズムとしては正しくなさそう

csenet, 2023-06-30:
やはりダイクストラ法なのかな

kienn-HCl, 2023-06-30:
うーん、そもそも経路決定で最短経路を求める必要があるんだろうか？
もっと経路の決定の仕方を煮詰めていったら最短経路求める必要なさそうな気がする。
からもうちょっと経路決定アルゴリズムを議論したほうがいいと思うな

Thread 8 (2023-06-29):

アーキテクチャを決定する

csenet, 2023-06-29:
# やりたいこと

実装を始めるにあたって、アーキテクチャを設計する。

# 実装の方針

前年度の内容をもとにして、今年度やりたいことをもとにしてソフトウェアとハードウェアを含めた全体のアーキテクチャ設計をする。

csenet, 2023-06-29:
# 今年度やりたいこと
**MUST**
- 列車の自動運転の実現
- デバッグがしやすいアーキテクチャの設計

**HAD BETTER**
- 信号機の実装
- 見て点楽しいWeb UIの実装

csenet, 2023-06-29:
現時点での暫定的なあアーキテクチャ図を添付する

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

csenet, 2023-06-30:
# 自動運転
昨年度は実装できなかった部分であるので、1から実装をする必要がある。
アルゴリズムの実装に関しては既に #7 にて議論している。路線の状態をグラフとして管理をする。
アルゴリズムにデータを渡すために色々をしなくてはいけないので、その部分に関しては別途実装する。

# 管理サイト
基本的にやりたいこととしては去年のサイトと同じだが、今回は状態を同期するためのプロトコルとしてconnect-webを採用したい。また、プラレールのレイアウトが微妙に変化することが予想されるのでフロントエンドの調整（SVG手打ち芸）が必要だが、可能ならこの部分を簡単にできるとなおよい。

# 状態管理
これまでとは異なるアーキテクチャで、列車の状態管理をモダンなIoTのアーキテクチャに近づけていきたい。
AWS IoTやAzureなどで利用されているアーキテクチャを模倣する感じで、MQTTでエッジの端末と通信してIOの状態の対応付けをバックエンド側で行うようにする。この部分は正直なところ、MongooseOSなどの既存の仕組みがあるが余裕があれば独自実装したい。
これまでは、KVSで管理していたがPodが死ぬと状態が失われるためアーキテクチャとしてはあまり良くない。
今回はアクセス頻度などを考慮して、MongoDBなどのNoSQLなDBで状態管理を行いたい。

# 列車検知
これまでのホールセンサーやCdSでは読み飛ばしが多くあった。今回はそうしたデータの読み飛ばしをなくすために、マイクロスイッチを用いた列車の通過検知と、列車が駅に停車した際にNFCタグを用いて列車を識別するような仕組みを実装したい。
基本手にはハードウェア側で大規模な処理をするわけではなく、イベントをhttp経由で通知してくれれば良い。（MQTTを採用するメリットは薄いような気もするがプロトコルの検討は必要かも）

# ポイント・ストップレール制御
昨年度と同様にESP32にサーボモータを接続して制御を行うことを検討している。
昨年度からの違いとして、MQTTでブローカーと接続してあげることで現地会場でのサーバー構築作業がなくなるので良さそうかなと思っている。httpよりも薄い感じのプロトコルらしく、普通にESPで問題なく動きそう。
ベースとなるコードはあるものの、実装が大きく変わるのでソースコードの変更は必要。

# カメラ配信
昨年度と同様にしてSkyWayを用いた映像中継を検討している。
車載カメラにはESP-EYEを採用してmjpegなどで受け取った映像を配信用PCからSkyWayに流すことを検討。
旧SkyWayがサービス終了するらしいので実装の変更は必要かもしれない。

# ラジコン
ラジコンに関してはTWILITEを用いた速度制御を行うことで安定性の向上を目指したい。
基盤に関しては昨年にスバル君が作ってくれたものがあるので、今回はこれを基盤におこして小型化を目指したい。
また重心問題にも対応できるなら尚良い。

csenet, 2023-07-02:
自動運転周りで色々とアーキテクチャが更新されたので変更

```mermaid
flowchart RL
subgraph 状態管理
管理画面 <-->|"connect-web"| StateManager
StateManager <-->|"MQTT"| Servo
EventHandler <-->|"connect"| StateManager
StateManager <--> DB1[(state_db)]
end
subgraph 自動運転
Sensor -->|"MQTT"| EventHandler
TrainController <--> StateManager
DiagramManager --> PathPlanner
PathPlanner <--> TrainController
DiagramManager <--> DB2[(diagram_db)]
DiagramManager <-->|"connect-web"| 管理画面
end
subgraph 映像配信
ESP-EYE -->|"mjpeg"| 配信サイト
配信サイト -->|"WebRTC"| SkyWay
SkyWay -->|"WebRTC"| 管理画面
end
```

kienn-HCl, 2023-07-02:
StateManagerからservoつなぐの？
StateManagerが持ってるのは物理世界を抽象化した線路図のグラフだから直接のやり取りは無理でTrainControllerにservoを動かすのをやってもらうんじゃないの？

csenet, 2023-07-02:
StateManagerが物理世界のグラフと路線図のグラフを両方持っていて(これはフロントエンドでの表示でも使うため)、TrainControllerはStateManagerが持ってる物理世界の状態を更新することによってサーボが動く想定をしてる

kienn-HCl, 2023-07-02:
物理世界のグラフって何をさしてるの
サーボ（ストップレールとポイント）の状態？

csenet, 2023-07-02:
グラフという表現は間違ってたかも。
はい、サーボの状態という意味です。

kienn-HCl, 2023-07-02:
なるほど、その場合ってstateManagerのサーボの状態をもとに物理世界へのサーボに指令を出すサービスを間に挟まなくていいの？

csenet, 2023-07-02:
その部分の認識がちょっと違うかもしれない
正確には、ESP32側が状態を常に監視してサーバー上のサーボの状態に合わせようとするという感じかな

kienn-HCl, 2023-07-02:
あー、なるほど

kienn-HCl, 2023-07-02:
前言ってたMQTTのサブスクライバとパブリッシャーのアーキテクチャの話か？

csenet, 2023-07-02:
そうだね。MQTTのPub/Subを上手に使うためにそうゆう設計が良いかなと
具体的に、デバイスは初回起動時にhttpのGETっぽいメソッドを呼び出して仮想のそうである状態を取得してきて、それ以降は状態が更新されるたびに発行されるtopicをサブスクライブして変更が発生したら物理的な状態を更新するイメージ。

参考
https://docs.aws.amazon.com/ja_jp/iot/latest/developerguide/device-shadow-data-flow.html

csenet, 2023-07-03:
フロントエンドとStateManager間の通信をGraphQLにしても良いかもしれない...？

csenet, 2023-07-16:
ref #62

csenet, 2023-09-15:
よくよく考えたら、State Managerにおいて一括で状態を管理するのはMircoservice archtectureに反しているような気がしてきた。あと、フロントエンドとの通信をいい感じにするためにBFF(Backend For Frontend)を追加してあげると良さそう。
少し設計を見直す。

csenet, 2023-09-16:
オライリー本を読んだ感じ、同じ状態を用いるコンポーネントが存在する場合に、その共通の状態を管理するサービスを用意するのは正しそう。
ただ、今回の場合はState Managerにおける責務が大きすぎる気がするので修正する。

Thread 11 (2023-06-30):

TWILITEを用いてプラレールを遠隔操作するラジコンを作る

csenet, 2023-06-30:
# やりたいこと

TWILITEを用いてプラレールの速度をコントローラから遠隔制御できるようなラジコンを実装する
昨年度はBLEを用いて実装を行っていたが、TWILITEの方が安定的に通信が行えるようなので変更したい。

# やること

- TWILITEを用いて遠隔でモータの速度制御ができるような基板を作成する
- 可能ならコントローラを作成する(電車でGOとかのコントローラを改造するといい感じかもしれない)

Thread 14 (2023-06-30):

管理画面のSVGに対応したエディタを作る

csenet, 2023-06-30:
# やりたいこと
現状の実装ではSVGを絶対座標で手打ちしているため、レイアウト変更するたびに変更するのがかなり大変
そこで、何かしらでGUI上で編集してComponentを吐けるようなエディタを作りたい

# やること
現状の管理画面の実装を把握して、何かしらでGUIで操作が行えるようなエディタを作る

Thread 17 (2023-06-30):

状態管理するためのStateManagerを実装する

csenet, 2023-06-30:
# やりたいこと
列車の閉塞の情報や各ストップレールなどの情報を管理して、物理的なハードウェアの状態と統一するための状態管理をするサービスを作る

# やること
- 仕様を決定する(protobufを書く)
- 利用するDBを決定する
- MQTTブローカーを構築する
- 状態の変更を通知する仕組みを実装する(MQTT)
- 状態の変更をフロント側に通知する仕組みを実装する(connect)
- auto operationからデータを受け取れるようにする

# 補足情報
通信プロトコルでconnectを利用する関係でgolangによる実装を推奨する

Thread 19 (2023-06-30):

列車の通過情報をMQTTで送信するコードを書く

csenet, 2023-06-30:
# やりたいこと
列車の通過や駅へ停車した際にpublishするための仕組みを実装する

# やること
列車が通過したことを #9 にて検知するので、このデータをMQTTで特定のtopicに対してpublishする
また、列車が駅に到着した際に列車の情報と駅の情報を特定のtopicにpublishする

csenet, 2023-11-08:
#193 にて一緒に完了

Closed 2023-11-08.

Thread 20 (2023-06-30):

NFCで列車の情報を読み取る仕組みを作る

csenet, 2023-06-30:
# やりたいこと
駅に停止した際にNFCタグから情報を読み取って列車の情報を取得する

# やること
- ESPを用いてNFCのデータをリーダーで読みとるプログラムを実装する
- 列車を識別するロジックを考える

csenet, 2023-09-16:
1台のESPにおいて最大で4台のRFIDリーダーを利用することを検討している。
この場合に動作することができるのかを検証したい。

SPI通信のSSを切り替えることによって読み取り先を変更することができるが、正しく動作するのかなどの感じを調べたい。もし、問題があるようならリーダーごとにESPを別途用意するなどの方法も検討したい。
https://github.com/miguelbalboa/rfid/blob/af76d16ee177be77c32ec5573b597b5d49c8cf1a/examples/ReadUidMultiReader/ReadUidMultiReader.ino

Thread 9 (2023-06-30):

列車の通過検知をするための部品を設計する

csenet, 2023-06-30:
# やりたいこと
これまでは列車の通過検知をCdSやホールセンサなどの不確定なもので行ってきたが、今回はマイクロスイッチを用いた在線検知を行いたい。

# やること
-プラレールへの取り付け部品を設計する
- ESP32で動作するシンプルなプログラムを実装して動作の検証をする
- 列車が通過するときに複数回検知しないことが理想

# 実装の方針
マイクロスイッチは共通規格で用意するので、これを用いて列車の通過を検知できるような部品を設計する。

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

csenet, 2023-10-24:
動作の検証までできたので完了

Closed 2023-10-24.

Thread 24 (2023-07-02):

Trainの現在地を表示するComponentを追加する

csenet, 2023-07-02:
# やりたいこと

列車の現在位置を状態として持っているので、路線図上に表示したい。

# やること

新しく列車の状態を表示するComponentを作る。

# 仕様

列車Componentで表示したい情報は以下の2点
 - 列車ID（stringで与えられるものでプラレールの識別に利用する。`azusa`や`naritaex`など列車と対応されることを想定）
 - プライオリティ（簡単にいうと特急や各駅などの種別で、数値として与えられる。種類は多くて3程度で、色などで区別したい）

Related to #14

コードを見る限り、Railにtrainsのpropsは定義されてるが実装がない状況

csenet, 2023-07-02:
なんとなく考えたイメージ図
もっと良いUIがあれば募集
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

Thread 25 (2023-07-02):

通信のプロトコルを決定する

csenet, 2023-07-02:
# やりたいこと
それぞれのマイクロサービス間での通信を行うためのプロトコルの仕様を決定する
具体的には以下の仕様を決定する必要がある

- 列車と閉塞情報の表現
- サーボの状態の表現

# やること
以上にあげた表現方法を考えた上で、protobufファイルを書き、ドキュメントにまとめる

# 補足
他のサービスの開発で必要となってくるので、なるべく早めに決定させたい

Closed 2023-09-09.

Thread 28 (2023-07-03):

管理画面UIの実装

csenet, 2023-07-03:
# やりたいこと
管理画面を実装する

# やること
- UIの設計を決める
- Next.jsで実装するComponentを作る

Mimi1008-tech, 2023-11-22:
進捗
`Background` 背景描画用
`Platform` 駅（`Station`に名前変更したほうがよい？）
`Rail`線路
`SwitchPoint`ポイント
`TraficLight`信号機
`Train`電車

を作成（昨年のコードを改良→Nextっぽくした＆色の設定をCSSで行えるようにした）

電車に関しては
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
こんな感じのものを作ってはある（座標指定可能）

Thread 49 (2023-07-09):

ドキュメント編集方法についてのドキュメント作成

csenet, 2023-07-09:
# やりたいこと

現状だとmdbookの使い方に関するドキュメントが存在しないため，ドキュメントを書くためのドキュメントを作成する

# やること

以下の内容に関するドキュメントを作成する。
1. ローカル上でのmdbookの導入方法
2. ドキュメント作成に関する決まりなど(どこのどのドキュメントを配置するか)
3. mdbookの編集方法 (SUMMARY.mdの使い方など)
4. デプロイ方法(GithubでPRを出す)

kienn-HCl, 2023-07-09:
前からやろうと思ってたけど後回しにしてたのだ…
やります

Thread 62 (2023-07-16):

現実世界との同期についての提案

csenet, 2023-07-16:
現状だと現実世界の同期の部分が少し冗長な気がした。MQTTの通信にはMQTT Brokerを用意しないといけないが、エンドポイントが2つに増えるよりは1つのMQTT Brokerで管理した方が良いような気がする。

```mermaid
flowchart RL
subgraph 状態管理
管理画面 <-->|"connect-web"| StateManager

MqttBroker <-->|"connect"| StateManager
StateManager <--> DB1[(state_db)]
end
subgraph 自動運転
TrainController <--> StateManager
DiagramManager --> PathPlanner
PathPlanner <--> TrainController
DiagramManager <--> DB2[(diagram_db)]
DiagramManager <-->|"connect-web"| 管理画面
end
subgraph 映像配信
Webカメラ --> |"USB"| 配信サイト
ESP-EYE -->|"mjpeg"| 配信サイト
配信サイト -->|"WebRTC"| SkyWay
SkyWay -->|"WebRTC"| 管理画面
end
subgraph エッジデバイス
MqttBroker  <-->|"MQTT"| Servo
Sensor -->|"MQTT"| MqttBroker
end
```

プロトコルはMqttで共通なので、MqttBrokerが全てのMqttの通信を担うようにして、StateManagerに対して状態の更新と、StateManaegrが受け取ったポイントの切り替えの指示などをMQTTで流すようにする。

こんな感じの構成に変更するのどうでしょうか？

Closed 2023-09-09.

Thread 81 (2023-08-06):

UIのコンポーネントをSVGに戻す

hutinoatari, 2023-08-06:
### やること

<!-- 目的としていることは何か -->
現在はreact-konvaを使っているが手打ちSVGに戻す。

### やること

<!-- 何をしなければいけないか -->
dragイベントで配置を変更できるようにする。

### 実装方法

<!-- 実装方法が決まっていれば -->
線路コンポーネントはエディタ用と表示用で分ける。
エディタ用は点を掴めるようにする。

## その他

<!-- 関連して何か気がついたこと、気になることがあれば書いてください -->
UI部の本格的な開発が始まる前にやっておきます。

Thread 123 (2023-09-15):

タスクを切り出す

csenet, 2023-09-15:
### やること

やることの内容がパンクしそうなので、他の人に頼める程度までタスクを切り出す

### やること

ある程度のアーキテクチャ設計をする
それぞれのタスクに対するIssueを用意する

### 実装方法

頑張る

## その他

<!-- 関連して何か気がついたこと、気になることがあれば書いてください -->

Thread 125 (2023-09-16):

IoTレイヤの設計

csenet, 2023-09-16:
### やること

現状ではStateManagerにおいて全ての状態を管理するという設計にしているが、内部的にはソフトウェアレイヤでの状態と、物理レイヤでの状態の2つが存在している。
ここでは、物理レイヤに注目して最低限のIoTシステムを設計する。

### やること

各種ESPとの通信、物理レイヤの状態管理を行うサービスを設計する。
その上で、必要となるサービスを実装する。

### 実装方法

MQTTでは以下の要素が必要となる。

- Broker
- Client

ここで、Brokerは異なるクライアント間でメッセージを調整するサービスであり、自前で実装するのは難しそうなので「Mosquitto」など利用する。

MQTT over TLSなどで暗号化機能をつけることも可能で本来であればそうするべきなのだが、今回の場合はひとまずセキュリティ機構をなしで実装する。

一緒にハードウェア側の仕様も決定しないとまずいかもしれない。

## その他

<!-- 関連して何か気がついたこと、気になることがあれば書いてください -->

csenet, 2023-09-16:
・ESP側の構成の検討
今回のハードウェア側で必要となる要素は以下の通り。
- サーボモータ（ストップレール、ポイント）
- 通過検知（スイッチ）
- 在線検知（NFC）
このうち、NFCを除いた部分においてはハードウェアを共通化したい。多分できると思う。
NFCに関しては、 #20 に関連して4台のリーダーを1つのESPで読み取ることができならばより良い。

それぞれのセンサーごとに対応するTopicを用意してあげて、サーボ周りに関してはSubscribe、在線検知に関してはPublishする。ソフトウェアとしては、Configファイルをメモリとかにおいてあげて、それを読み込むような設定にしてあげると良さげな気がする。

csenet, 2023-11-08:
#193 にて設計を決定してコードを書けたので終了

Closed 2023-11-08.

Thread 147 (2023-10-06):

シミュレーターでアルゴリズムの動作を確認する

csenet, 2023-10-06:
### やりたいこと

#7 にて検討しているアルゴリズムに関して実際にPythonやGolangなどの言語で簡単なシミュレーターを実装してみて、アルゴリズムの問題点などを確認したい。

### やること

- 任意の言語でシミュレーターを実装する
- 様々な条件下において問題なく動作することを確かめる

### 実装方法

グラフで閉塞や列車の情報を管理してそれを元にアルゴリズムが動作するので、Objectで良い感じにデータ表現をしてあげて動くことを確認する。

## その他

<!-- 関連して何か気がついたこと、気になることがあれば書いてください -->

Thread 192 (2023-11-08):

カメラ機能の実装

csenet, 2023-11-08:
### やりたいこと

車載カメラ機能を実装したい

### やること

- カメラ配信の仕組みを考える
- ESP-EYE用のコードを書く
- バッテリーを考える

### 実装方法

車載カメラ用にESP-EYEをつかって、UDPで映像を送ってサーバー側で処理してリアルタイムで映像を出す。

## その他

<!-- 関連して何か気がついたこと、気になることがあれば書いてください -->

McbeEringi, 2023-11-13:
esp-eye→nodejs→ブラウザは出来上がった
始終mjpeg
あきたかも

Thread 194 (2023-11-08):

各種サーバのコンテナイメージをactionsで作成する

Azuki-bar, 2023-11-08:
### やりたいこと

<!-- 目的としていることは何か -->

### やること

<!-- 何をしなければいけないか -->

### 実装方法

<!-- 実装方法が決まっていれば -->

## その他

<!-- 関連して何か気がついたこと、気になることがあれば書いてください -->

goはマルチプラットフォームイメージにして、他はx86_64のみにする

Closed 2023-11-08.

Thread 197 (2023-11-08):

GPIO管理Managerの実装

csenet, 2023-11-08:
### やりたいこと

会場に設置するESP32に対して、接続の設定を個別にプログラムで書き込むのではなく、ESP32側が動的に取得して反映できるようにしたい。
具体的には、ハードウェア上に接続したピンの名前とIDを対応づけられるようにしたい。

### やること

1. ESP32の端末ごとに何かしらの方法で個別の識別IDを付与する
2. MQTT経由で設定を取得する
3. 配信する設定をサーバー側で管理できるようにする

### 実装方法

HardwareManagerか何かしらを用意して、その上で設定を管理できるようにする。
合わせてフロントエンドも作る。

## その他

<!-- 関連して何か気がついたこと、気になることがあれば書いてください -->

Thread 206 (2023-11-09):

State Managerでpprofできるようにする

Azuki-bar, 2023-11-09:
### やりたいこと

<!-- 目的としていることは何か -->
落ちるらしいのでメモリ使用量とかを計測

pprofじゃなくてOTel対応とかでも良いかも
### やること

<!-- 何をしなければいけないか -->

### 実装方法

<!-- 実装方法が決まっていれば -->

## その他

<!-- 関連して何か気がついたこと、気になることがあれば書いてください -->

Closed 2023-11-10.

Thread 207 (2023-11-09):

State managerがgracedul shutdownできるようにする

Azuki-bar, 2023-11-09:
### やりたいこと

<!-- 目的としていることは何か -->
コンテナで動かすにあたってgraceful shutdownするようにしたい

### やること

<!-- 何をしなければいけないか -->
mainでcontextを作って、goroutineで呼んでいる関数に渡す

ctxを適切にバンドルする
### 実装方法

<!-- 実装方法が決まっていれば -->

## その他

<!-- 関連して何か気がついたこと、気になることがあれば書いてください -->

Closed 2023-11-10.

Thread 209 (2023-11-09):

golangのlinterを入れる

Azuki-bar, 2023-11-09:
### やりたいこと

<!-- 目的としていることは何か -->
goにも他言語と同じように踏みやすいトラップがあるので避ける

### やること

<!-- 何をしなければいけないか -->
golangci-lintを入れる

どこかにいい感じルールは落ちているはず
### 実装方法

<!-- 実装方法が決まっていれば -->

## その他

<!-- 関連して何か気がついたこと、気になることがあれば書いてください -->

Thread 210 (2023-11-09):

コンテナイメージのタグにブランチの情報を含める

Azuki-bar, 2023-11-09:
### やりたいこと

<!-- 目的としていることは何か -->
今のコンテナイメージのタグは `git.sha1[0:6]-unixtimestamp` で出来ている。
developmentブランチでも一部はpushするようにしたのでunix-timestampでソートするとdevelopmentブランチのイメージが本番環境に適用される。

なのでタグにブランチ名を入れるとかする必要がある。

### やること

<!-- 何をしなければいけないか -->

### 実装方法

<!-- 実装方法が決まっていれば -->

## その他

<!-- 関連して何か気がついたこと、気になることがあれば書いてください -->

Closed 2023-11-18.

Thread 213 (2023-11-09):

goのプログラムにslog入れる

Azuki-bar, 2023-11-09:
### やりたいこと

<!-- 目的としていることは何か -->

go 1.21からslogが標準になったことだし入れる
デバッグとかやりやすくなるはず。

環境を表現する環境変数←トンチ？が欲しいね。 APP_ENVみたいなやつ
### やること

<!-- 何をしなければいけないか -->

### 実装方法

<!-- 実装方法が決まっていれば -->

## その他

<!-- 関連して何か気がついたこと、気になることがあれば書いてください -->

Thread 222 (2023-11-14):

release PRを自動で作る

Azuki-bar, 2023-11-14:
### やりたいこと

<!-- 目的としていることは何か -->

plarail2023ではdeploymentブランチに対してPRを発行しマージされるとイメージの作成が始まる。

ueckoken/plarail2022 でhgit-pr-releaseを用いてPRを自動生成していたので導入したい
### やること

<!-- 何をしなければいけないか -->

### 実装方法

<!-- 実装方法が決まっていれば -->

git-pr-releaseとか入れる。より良い手段があればそれでも。
## その他

<!-- 関連して何か気がついたこと、気になることがあれば書いてください -->

Closed 2023-11-14.

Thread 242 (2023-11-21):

Ctrl + Cでプロセスが終了しない

csenet, 2023-11-21:
<!-- どの部分での不具合かを示すラベルの追加をお願いします -->

## 不具合の内容

<!-- 概要を記入してください -->

現状「state-manager」を実行した状態で、Ctrl + Cでプロセスを終了しようとしても落ちない。

### 現象・ログ

<!-- どのような問題が発生しているか具体的に記入してください -->
Ctrl + Cを押すと、
```
2023-11-21T16:22:53.367548+09:00 INFO signal received
```
と表示された後、一向に終了しない。

### 再現手順

<!-- どのような操作をしてそうなったかを記入してください -->
main.goを実行して、Ctrl + Cで終了を試みる。

### 期待動作

<!-- 正しいと思う動作が明確であれば記載してください -->
Ctrl + Cで正常に終了する。

## その他

<!-- 関連して何か気がついたこと、気になることが記入してください -->

Azuki-bar, 2023-11-21:
心当たりあります

Closed 2023-11-21.

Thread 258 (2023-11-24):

デプロイ環境の整備

csenet, 2023-11-24:
### やりたいこと

<!-- 目的としていることは何か -->
会場でサーバーを用意する

### やること

<!-- 何をしなければいけないか -->
- auto-operatio用のDocker Imageの作成
- 本番環境用のdocker composeを作成
- cloud flare tunnelで繋げる

### 実装方法

<!-- 実装方法が決まっていれば -->

## その他

<!-- 関連して何か気がついたこと、気になることがあれば書いてください -->

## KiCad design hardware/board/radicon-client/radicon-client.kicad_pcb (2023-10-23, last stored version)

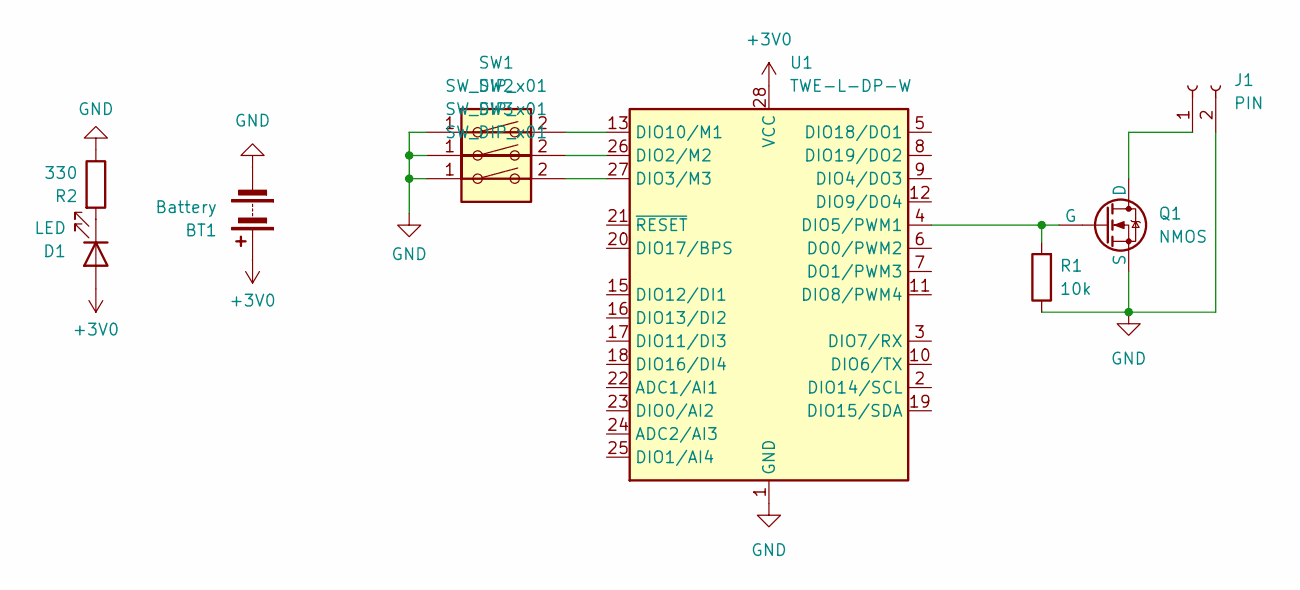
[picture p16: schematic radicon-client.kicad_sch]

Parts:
BT1: Battery; BatteryHolder_Keystone_103_1x20mm
D1: LED; LED_D3.0mm
J1: PIN; JST_PH_S2B-PH-K_1x02_P2.00mm_Horizontal
Q1: NMOS; TO-252-2
R1: 10k; R_Axial_DIN0207_L6.3mm_D2.5mm_P10.16mm_Horizontal
R2: 330; R_Axial_DIN0207_L6.3mm_D2.5mm_P10.16mm_Horizontal
SW1, SW2, SW3: SW_DIP_x01; SolderJumper-2_P1.3mm_Open_TrianglePad1.0x1.5mm
U1: TWE-L-DP-W; DIP-28_W15.24mm

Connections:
+3V0: BT1.1 (+), D1.2 (A), U1.28 (VCC)
GND: BT1.2 (-), J1.2, Q1.3 (S), R1.1, R2.1, SW1.1, SW2.1, SW3.1, U1.1 (GND), U1.14 (GND)
unnamed: D1.1 (K), R2.2
unnamed: J1.1, Q1.1 (D)
unnamed: Q1.2 (G), R1.2, U1.4 (DIO5/PWM1)
unnamed: SW2.2, U1.26 (DIO2/M2)
unnamed: SW3.2, U1.27 (DIO3/M3)
unnamed: SW1.2, U1.13 (DIO10/M1)

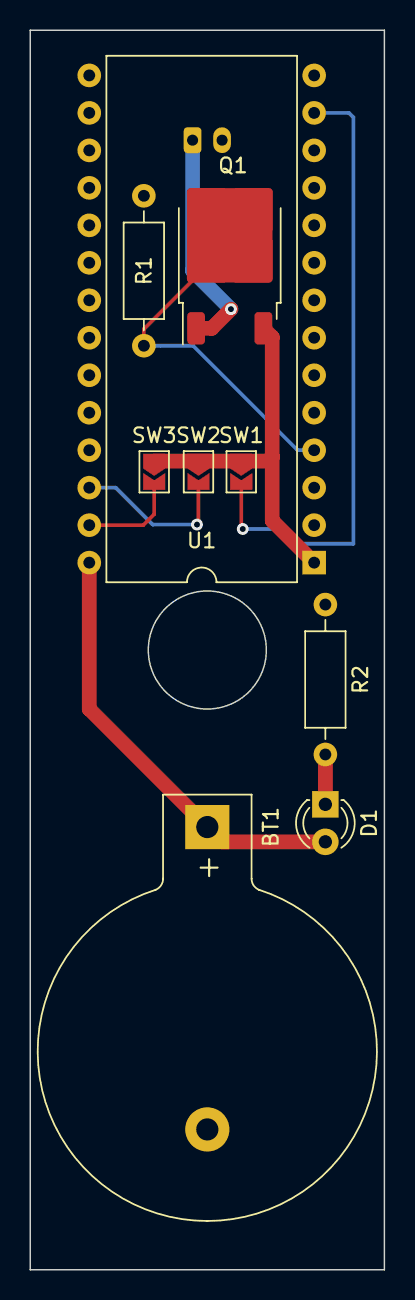
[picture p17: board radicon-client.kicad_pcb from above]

Board: 2 copper layers, 24.0 x 84.0 mm, 10 parts (1 on the bottom side), 8 nets.

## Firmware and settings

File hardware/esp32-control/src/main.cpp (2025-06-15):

#include <Arduino.h>
#include <PubSubClient.h>
#include <WiFi.h>
#include <WiFiClient.h>
#include <ESP32Servo.h>
#include <ArduinoOTA.h>
#include <LittleFS.h>
#include <ESPmDNS.h>

// Include the header file of the library
#include "PassDetector.h"
#include "PointRail.h"
#include "StopRail.h"
#include "MQTTSetting.h"
#include "Settings.h"
#include "TopicRouter.h"
#include "SettingLoader.h"
#include "IOManager.h"

#define DEBUG

#define SPI_SCK 0
#define SPI_MISO 2
#define SPI_MOSI 1

// MQTT Broker
WiFiClient espClient;
PubSubClient client(espClient);
IOManager manager(&client);

void callback(char *topic, byte *payload, unsigned int length);
void reconnect(); // 再接続関数を追加

void setup()
{
  Serial.begin(115200);

  // PubSubClientのバッファサイズを増やす（デフォルト256から1024へ）
  client.setBufferSize(1024);

  // WiFiに接続
  Serial.println("-----Welcome to Plarail IoT System!-----");
  WiFi.begin(ssid, password);
  Serial.print("MAC Address: ");
  Serial.println(WiFi.macAddress());
  while (WiFi.status() != WL_CONNECTED)
  {
    delay(500);
    Serial.print(".");
  }
  Serial.printf("\nIP address: %s\n", WiFi.localIP().toString().c_str());

  // LittleFS初期化
  if (!LittleFS.begin(FORMAT_LITTLEFS_IF_FAILED))
  {
    Serial.println("LittleFS Mount Failed");
    return;
  }

  // // SPIを初期化
  // SPI.begin(SPI_SCK, SPI_MISO, SPI_MOSI);

  // 設定ファイルを読み込む
  getSetting(&manager);

  if (!SETTING_LOADED)
  {
    Serial.println("Setting File Not Found");
    return;
  }

  // MDNSを開始
  MDNS.begin(HOST);

  // espClient.setCACert(root_ca);
  client.setServer(mqtt_broker, mqtt_port);
  client.setCallback(callback);
  client.setKeepAlive(60);     // KeepAliveを60秒に設定
  client.setSocketTimeout(30); // ソケットタイムアウトを30秒に設定

  reconnect(); // 初回接続を再接続関数で行う

  // 初期状態を取得
  manager.getInitialState();
}

// 再接続関数を追加
void reconnect()
{
  while (!client.connected())
  {
    String client_id = "esp32-client-";
    client_id += String(HOST);
    Serial.printf("The client %s connects to the public mqtt broker\n", client_id.c_str());

    if (client.connect(client_id.c_str(), mqtt_username, mqtt_password))
    {
      Serial.println("MQTT connected");
      // 再接続時にTopicを再購読
      client.subscribe("stop/+/get/accepted");
      client.subscribe("point/+/get/accepted");
      client.subscribe("stop/+/delta");
      client.subscribe("point/+/delta");
      Serial.println("Topics resubscribed after reconnection");
    }
    else
    {
      Serial.print("failed with state ");
      int state = client.state();
      Serial.print(state);
      switch (state)
      {
      case -4:
        Serial.println(" - MQTT_CONNECTION_TIMEOUT");
        break;
      case -3:
        Serial.println(" - MQTT_CONNECTION_LOST");
        break;
      case -2:
        Serial.println(" - MQTT_CONNECT_FAILED");
        break;
      case -1:
        Serial.println(" - MQTT_DISCONNECTED");
        break;
      case 1:
        Serial.println(" - MQTT_CONNECT_BAD_PROTOCOL");
        break;
      case 2:
        Serial.println(" - MQTT_CONNECT_BAD_CLIENT_ID");
        break;
      case 3:
        Serial.println(" - MQTT_CONNECT_UNAVAILABLE");
        break;
      case 4:
        Serial.println(" - MQTT_CONNECT_BAD_CREDENTIALS");
        break;
      case 5:
        Serial.println(" - MQTT_CONNECT_UNAUTHORIZED");
        break;
      default:
        Serial.println(" - Unknown error");
      }
      Serial.println("Retrying in 5 seconds...");
      delay(5000);
    }
  }
}

void callback(char *topic, byte *payload, unsigned int length)
{
#ifdef DEBUG
  Serial.print("Message arrived in topic: ");
  Serial.println(topic);
  Serial.print("Message:");
  for (int i = 0; i < length; i++)
  {
    Serial.print((char)payload[i]);
  }
  Serial.println();
  Serial.println("-----------------------");
#endif

  mqtt_handler(topic, payload, length, &manager);
}

void loop()
{
  // WiFi接続チェック
  if (WiFi.status() != WL_CONNECTED)
  {
    Serial.println("WiFi disconnected. Reconnecting...");
    WiFi.reconnect();
    delay(1000);
    return;
  }

  // MQTT接続チェック
  if (!client.connected())
  {
    Serial.println("MQTT disconnected. Reconnecting...");
    reconnect();
  }

  manager.loop();
  client.loop();
}

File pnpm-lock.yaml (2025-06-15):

lockfileVersion: '9.0'

settings:
  autoInstallPeers: true
  excludeLinksFromLockfile: false

importers:

  backend/auto-operation:
    dependencies:
      '@bufbuild/buf':
        specifier: ^1.28.1
        version: 1.28.1
      '@bufbuild/protobuf':
        specifier: ^1.4.2
        version: 1.4.2
      '@connectrpc/connect':
        specifier: ^1.1.3
        version: 1.1.3(@bufbuild/protobuf@1.4.2)
      '@connectrpc/connect-node':
        specifier: ^1.1.3
        version: 1.1.3(@bufbuild/protobuf@1.4.2)(@connectrpc/connect@1.1.3(@bufbuild/protobuf@1.4.2))
      '@connectrpc/connect-web':
        specifier: ^1.1.3
        version: 1.1.3(@bufbuild/protobuf@1.4.2)(@connectrpc/connect@1.1.3(@bufbuild/protobuf@1.4.2))
      install:
        specifier: ^0.13.0
        version: 0.13.0
      ts-node:
        specifier: ^10.9.2
        version: 10.9.2(@swc/core@1.3.99(@swc/helpers@0.5.2))(@types/node@20.9.5)(typescript@5.2.2)
    devDependencies:
      '@bufbuild/protoc-gen-es':
        specifier: ^1.4.2
        version: 1.4.2(@bufbuild/protobuf@1.4.2)
      '@connectrpc/protoc-gen-connect-es':
        specifier: ^1.1.3
        version: 1.1.3(@bufbuild/protoc-gen-es@1.4.2(@bufbuild/protobuf@1.4.2))(@connectrpc/connect@1.1.3(@bufbuild/protobuf@1.4.2))
      '@types/node':
        specifier: 20.9.5
        version: 20.9.5
      tsx:
        specifier: ^4.3.0
        version: 4.3.0
      typescript:
        specifier: 5.2.2
        version: 5.2.2

  frontend/dashboard:
    dependencies:
      '@bufbuild/connect-web':
        specifier: ^0.13.0
        version: 0.13.0(@bufbuild/protobuf@1.4.2)
      '@bufbuild/protobuf':
        specifier: ^1.4.2
        version: 1.4.2
      '@connectrpc/connect':
        specifier: ^1.1.3
        version: 1.1.3(@bufbuild/protobuf@1.4.2)
      '@connectrpc/connect-query':
        specifier: ^0.6.0
        version: 0.6.0(@bufbuild/protobuf@1.4.2)(@connectrpc/connect@1.1.3(@bufbuild/protobuf@1.4.2))(@tanstack/react-query@5.8.4(react-dom@18.2.0(react@18.2.0))(react@18.2.0))(react-dom@18.2.0(react@18.2.0))(react@18.2.0)
      '@connectrpc/connect-web':
        specifier: ^1.1.3
        version: 1.1.3(@bufbuild/protobuf@1.4.2)(@connectrpc/connect@1.1.3(@bufbuild/protobuf@1.4.2))
      '@tanstack/react-query':
        specifier: ^5.8.4
        version: 5.8.4(react-dom@18.2.0(react@18.2.0))(react@18.2.0)
      clsx:
        specifier: ^2.0.0
        version: 2.0.0
      react:
        specifier: ^18.2.0
        version: 18.2.0
      react-dom:
        specifier: ^18.2.0
        version: 18.2.0(react@18.2.0)
      react-error-boundary:
        specifier: ^4.0.11
        version: 4.0.11(react@18.2.0)
      sass:
        specifier: ^1.69.5
        version: 1.69.5
    devDependencies:
      '@bufbuild/buf':
        specifier: ^1.28.1
        version: 1.28.1
      '@bufbuild/protoc-gen-connect-web':
        specifier: ^0.11.0
        version: 0.11.0(@bufbuild/connect@0.13.0(@bufbuild/protobuf@1.4.2))(@bufbuild/protoc-gen-es@1.4.2(@bufbuild/protobuf@1.4.2))
      '@bufbuild/protoc-gen-es':
        specifier: ^1.4.2
        version: 1.4.2(@bufbuild/protobuf@1.4.2)
      '@connectrpc/protoc-gen-connect-es':
        specifier: ^1.1.3
        version: 1.1.3(@bufbuild/protoc-gen-es@1.4.2(@bufbuild/protobuf@1.4.2))(@connectrpc/connect@1.1.3(@bufbuild/protobuf@1.4.2))
      '@connectrpc/protoc-gen-connect-query':
        specifier: ^0.6.0
        version: 0.6.0(@bufbuild/protoc-gen-es@1.4.2(@bufbuild/protobuf@1.4.2))
      '@types/node':
        specifier: 20.9.2
        version: 20.9.2
      '@types/react':
        specifier: ^18.2.37
        version: 18.2.38
      '@types/react-dom':
        specifier: ^18.2.15
        version: 18.2.17
      '@typescript-eslint/eslint-plugin':
        specifier: ^6.10.0
        version: 6.12.0(@typescript-eslint/parser@6.12.0(eslint@8.54.0)(typescript@5.3.2))(eslint@8.54.0)(typescript@5.3.2)
      '@typescript-eslint/parser':
        specifier: ^6.10.0
        version: 6.12.0(eslint@8.54.0)(typescript@5.3.2)
      '@vitejs/plugin-react-swc':
        specifier: ^3.5.0
        version: 3.5.0(@swc/helpers@0.5.2)(vite@5.0.2(@types/node@20.9.2)(sass@1.69.5)(terser@5.24.0))
      eslint:
        specifier: ^8.53.0
        version: 8.54.0
      eslint-config-prettier:
        specifier: ^9.0.0
        version: 9.0.0(eslint@8.54.0)
      eslint-plugin-react-hooks:
        specifier: ^4.6.0
        version: 4.6.0(eslint@8.54.0)
      eslint-plugin-react-refresh:
        specifier: ^0.4.4
        version: 0.4.4(eslint@8.54.0)
      prettier:
        specifier: 3.1.0
        version: 3.1.0
      typescript:
        specifier: ^5.2.2
        version: 5.3.2
      vite:
        specifier: ^5.0.0
        version: 5.0.2(@types/node@20.9.2)(sass@1.69.5)(terser@5.24.0)
      vite-plugin-svgr:
        specifier: ^4.2.0
        version: 4.2.0(rollup@4.5.1)(typescript@5.3.2)(vite@5.0.2(@types/node@20.9.2)(sass@1.69.5)(terser@5.24.0))
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

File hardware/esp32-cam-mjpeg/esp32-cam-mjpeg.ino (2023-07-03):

/*

  This is a simple MJPEG streaming webserver implemented for AI-Thinker ESP32-CAM and
  ESP32-EYE modules.
  This is tested to work with VLC and Blynk video widget.

  Inspired by and based on this Instructable: $9 RTSP Video Streamer Using the ESP32-CAM Board
  (https://www.instructables.com/id/9-RTSP-Video-Streamer-Using-the-ESP32-CAM-Board/)

  Board: AI-Thinker ESP32-CAM

*/

#include "OV2640.h"
#include <WiFi.h>
#include <WebServer.h>
#include <WiFiClient.h>

// Select camera model
//#define CAMERA_MODEL_WROVER_KIT
#define CAMERA_MODEL_ESP_EYE
//#define CAMERA_MODEL_M5STACK_PSRAM
//#define CAMERA_MODEL_M5STACK_WIDE
//#define CAMERA_MODEL_AI_THINKER

#include "camera_pins.h"

#define SSID ""
#define PWD ""

OV2640 cam;

WebServer server(80);

const char HEADER[] = "HTTP/1.1 200 OK\r\n" \
                      "Access-Control-Allow-Origin: *\r\n" \
                      "Content-Type: multipart/x-mixed-replace; boundary=123456789000000000000987654321\r\n";
const char BOUNDARY[] = "\r\n--123456789000000000000987654321\r\n";
const char CTNTTYPE[] = "Content-Type: image/jpeg\r\nContent-Length: ";
const int hdrLen = strlen(HEADER);
const int bdrLen = strlen(BOUNDARY);
const int cntLen = strlen(CTNTTYPE);

void handle_jpg_stream(void)
{
  char buf[32];
  int s;

  WiFiClient client = server.client();

  client.write(HEADER, hdrLen);
  client.write(BOUNDARY, bdrLen);

  while (true)
  {
    if (!client.connected()) break;
    cam.run();
    s = cam.getSize();
    client.write(CTNTTYPE, cntLen);
    sprintf( buf, "%d\r\n\r\n", s );
    client.write(buf, strlen(buf));
    client.write((char *)cam.getfb(), s);
    client.write(BOUNDARY, bdrLen);
  }
}

const char JHEADER[] = "HTTP/1.1 200 OK\r\n" \
                       "Content-disposition: inline; filename=capture.jpg\r\n" \
                       "Content-type: image/jpeg\r\n\r\n";
const int jhdLen = strlen(JHEADER);

void handle_jpg(void)
{
  WiFiClient client = server.client();

  if (!client.connected()) return;
  cam.run();
  client.write(JHEADER, jhdLen);
  client.write((char *)cam.getfb(), cam.getSize());
}

void handleNotFound()
{
  String message = "Server is running!\n\n";
  message += "URI: ";
  message += server.uri();
  message += "\nMethod: ";
  message += (server.method() == HTTP_GET) ? "GET" : "POST";
  message += "\nArguments: ";
  message += server.args();
  message += "\n";
  server.send(200, "text / plain", message);
}

void setup()
{

  Serial.begin(115200);
  //while (!Serial);            //wait for serial connection.

  camera_config_t config;
  config.ledc_channel = LEDC_CHANNEL_0;
  config.ledc_timer = LEDC_TIMER_0;
  config.pin_d0 = Y2_GPIO_NUM;
  config.pin_d1 = Y3_GPIO_NUM;
  config.pin_d2 = Y4_GPIO_NUM;
  config.pin_d3 = Y5_GPIO_NUM;
  config.pin_d4 = Y6_GPIO_NUM;
  config.pin_d5 = Y7_GPIO_NUM;
  config.pin_d6 = Y8_GPIO_NUM;
  config.pin_d7 = Y9_GPIO_NUM;
  config.pin_xclk = XCLK_GPIO_NUM;
  config.pin_pclk = PCLK_GPIO_NUM;
  config.pin_vsync = VSYNC_GPIO_NUM;
  config.pin_href = HREF_GPIO_NUM;
  config.pin_sscb_sda = SIOD_GPIO_NUM;
  config.pin_sscb_scl = SIOC_GPIO_NUM;
  config.pin_pwdn = PWDN_GPIO_NUM;
  config.pin_reset = RESET_GPIO_NUM;
  config.xclk_freq_hz = 20000000;
  config.pixel_format = PIXFORMAT_JPEG;

  // Frame parameters
  //  config.frame_size = FRAMESIZE_UXGA;
  config.frame_size = FRAMESIZE_QVGA;
  config.jpeg_quality = 12;
  config.fb_count = 2;

#if defined(CAMERA_MODEL_ESP_EYE)
  pinMode(13, INPUT_PULLUP);
  pinMode(14, INPUT_PULLUP);
#endif

  cam.init(config);

  IPAddress ip;

  WiFi.mode(WIFI_STA);
  WiFi.begin(SSID, PWD);
  while (WiFi.status() != WL_CONNECTED)
  {
    delay(500);
    Serial.print(F("."));
  }
  ip = WiFi.localIP();
  Serial.println(F("WiFi connected"));
  Serial.println("");
  Serial.println(ip);
  Serial.print("Stream Link: http://");
  Serial.print(ip);
  Serial.println("/mjpeg/1");
  server.on("/mjpeg/1", HTTP_GET, handle_jpg_stream);
  server.on("/jpg", HTTP_GET, handle_jpg);
  server.onNotFound(handleNotFound);
  server.begin();
}

void loop()
{
  server.handleClient();
}

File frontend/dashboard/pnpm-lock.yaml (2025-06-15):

lockfileVersion: '9.0'

settings:
  autoInstallPeers: true
  excludeLinksFromLockfile: false

importers:

  .:
    dependencies:
      '@bufbuild/connect-web':
        specifier: ^0.13.0
        version: 0.13.0(@bufbuild/protobuf@1.10.1)
      '@bufbuild/protobuf':
        specifier: ^1.4.2
        version: 1.10.1
      '@connectrpc/connect':
        specifier: ^1.1.3
        version: 1.6.1(@bufbuild/protobuf@1.10.1)
      '@connectrpc/connect-query':
        specifier: ^0.6.0
        version: 0.6.0(@bufbuild/protobuf@1.10.1)(@connectrpc/connect@1.6.1(@bufbuild/protobuf@1.10.1))(@tanstack/react-query@5.80.7(react@18.3.1))(react-dom@18.3.1(react@18.3.1))(react@18.3.1)
      '@connectrpc/connect-web':
        specifier: ^1.1.3
        version: 1.6.1(@bufbuild/protobuf@1.10.1)(@connectrpc/connect@1.6.1(@bufbuild/protobuf@1.10.1))
      '@tanstack/react-query':
        specifier: ^5.8.4
        version: 5.80.7(react@18.3.1)
      clsx:
        specifier: ^2.0.0
        version: 2.1.1
      react:
        specifier: ^18.2.0
        version: 18.3.1
      react-dom:
        specifier: ^18.2.0
        version: 18.3.1(react@18.3.1)
      react-error-boundary:
        specifier: ^4.0.11
        version: 4.1.2(react@18.3.1)
      sass:
        specifier: ^1.69.5
        version: 1.89.2
    devDependencies:
      '@bufbuild/buf':
        specifier: ^1.28.1
        version: 1.54.0
      '@bufbuild/protoc-gen-connect-web':
        specifier: ^0.11.0
        version: 0.11.0(@bufbuild/protoc-gen-es@1.10.1(@bufbuild/protobuf@1.10.1))
      '@bufbuild/protoc-gen-es':
        specifier: ^1.4.2
        version: 1.10.1(@bufbuild/protobuf@1.10.1)
      '@connectrpc/protoc-gen-connect-es':
        specifier: ^1.1.3
        version: 1.6.1(@bufbuild/protoc-gen-es@1.10.1(@bufbuild/protobuf@1.10.1))(@connectrpc/connect@1.6.1(@bufbuild/protobuf@1.10.1))
      '@connectrpc/protoc-gen-connect-query':
        specifier: ^0.6.0
        version: 0.6.0(@bufbuild/protoc-gen-es@1.10.1(@bufbuild/protobuf@1.10.1))
      '@types/node':
        specifier: 20.9.2
        version: 20.9.2
      '@types/react':
        specifier: ^18.2.37
        version: 18.3.23
      '@types/react-dom':
        specifier: ^18.2.15
        version: 18.3.7(@types/react@18.3.23)
      '@typescript-eslint/eslint-plugin':
        specifier: ^6.10.0
        version: 6.21.0(@typescript-eslint/parser@6.21.0(eslint@8.57.1)(typescript@5.8.3))(eslint@8.57.1)(typescript@5.8.3)
      '@typescript-eslint/parser':
        specifier: ^6.10.0
        version: 6.21.0(eslint@8.57.1)(typescript@5.8.3)
      '@vitejs/plugin-react-swc':
        specifier: ^3.5.0
        version: 3.10.2(vite@5.4.19(@types/node@20.9.2)(sass@1.89.2))
      eslint:
        specifier: ^8.53.0
        version: 8.57.1
      eslint-config-prettier:
        specifier: ^9.0.0
        version: 9.1.0(eslint@8.57.1)
      eslint-plugin-react-hooks:
        specifier: ^4.6.0
        version: 4.6.2(eslint@8.57.1)
      eslint-plugin-react-refresh:
        specifier: ^0.4.4
        version: 0.4.20(eslint@8.57.1)
      prettier:
        specifier: 3.1.0
        version: 3.1.0
      typescript:
        specifier: ^5.2.2
        version: 5.8.3
      vite:
        specifier: ^5.0.0
        version: 5.4.19(@types/node@20.9.2)(sass@1.89.2)
      vite-plugin-svgr:
        specifier: ^4.2.0
        version: 4.3.0(rollup@4.43.0)(typescript@5.8.3)(vite@5.4.19(@types/node@20.9.2)(sass@1.89.2))
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

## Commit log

2023-06-30 路線図エディタの実装
2023-07-02 SVGをkonvaに移植した
2023-07-11 冗長な表現を削除
2023-09-16 add proto and sample
2023-10-06 Update futurequest.md
    typoを修正
2023-10-14 deploy sample applciation
2023-10-14 remove sample app
2023-10-14 add sample app
2023-10-18 add board data
    [radicon-client-B_Cu.gbr, radicon-client-B_Mask.gbr, radicon-client-B_Paste.gbr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]
2023-10-23 update board
    [radicon-client-B_Cu.gbr, radicon-client-B_Mask.gbr, radicon-client-B_Paste.gbr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]
2023-10-24 Protoを大幅に修正
2023-11-04 NT東京用にState Managerの最低限の機能を追加
2023-11-08 remove boards
    [radicon-client-B_Cu.gbr, radicon-client-B_Mask.gbr, radicon-client-B_Paste.gbr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]
2023-11-08 specの場所を元に戻す
2023-11-08 Actionsでイメージをプッシュするようにした
2023-11-09 ghcrにプッシュする
2023-11-09 コメント書く
2023-11-09 かっこが1つ多かった
2023-11-09 終了条件が違う
2023-11-09 publicディレクトリも移動する
2023-11-09 contextを受ける
2023-11-09 graceful shutdownに対応する
2023-11-09 一応contextも受ける
2023-11-10 http routerをgo-chiにしてpprofを吐くようにする
2023-11-12 connect_handlerにロガーを仕込む。
2023-11-15 Add switch and MQTT settings
2023-11-16 イメージタグ名でdeploymentブランチであることを表現する
2023-11-19 NFCReaderとPassDetectorを追加
2023-11-21 http.Serverはcontextがdoneしたときにいい感じにエラーを返してくれない
2023-11-21 ioutilはDeprecated
2023-11-21 コメントを追加
2023-11-21 Remove ESP32 Cam UDP CI workflow
2023-11-21 DBとmqttのコネクションを使い回すようにした
2023-11-21 contextの名前を変える
2023-11-22 コンポーネント作成
2023-11-22 trainコンポーネントを修正
2023-11-24 backend/auto-operationをpnpmの管理下にいれる
2023-11-24 buildできるようにする
2023-11-24 イメージ作る
2023-11-24 キャッシュを掴まないようにする
2023-11-24 pnpmがおかしい
2023-11-24 pin version
2024-04-28 comment out unused buttons
2025-06-15 ハードウェアのリコネクトを追加
2025-06-15 Refactor Dockerfile for frontend dashboard: switch from distroless to nginx for serving static files and streamline build process
2025-06-18 データベース接続のクローズ処理を改善し、エラーハンドリングを強化。README.mdを追加し、State Managerの設定と起動方法を明記。
2025-06-18 レイアウトを修正
2025-06-18 Kubernetesマニフェストを追加し、各サービスのデプロイメント、サービス、PVCを定義。ローカル開発用のビルドおよびデプロイスクリプトを整備。
2025-06-19 各サービスのデプロイメントで使用するイメージをghcr.ioに変更し、imagePullPolicyをAlwaysに設定
2025-06-20 Seed Data実行スクリプトを追加し、環境に応じた設定とJobの管理機能を実装
2025-06-20 MapView: Update block IDs in onClick handlers for Rail components to ensure correct state mutation
